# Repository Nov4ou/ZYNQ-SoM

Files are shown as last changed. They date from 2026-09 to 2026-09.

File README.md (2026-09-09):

# ZYNQ-SoM

An open-source Zynq-7000 system-on-module, designed in KiCad. The Rev B boards have been assembled and tested.

## Photos

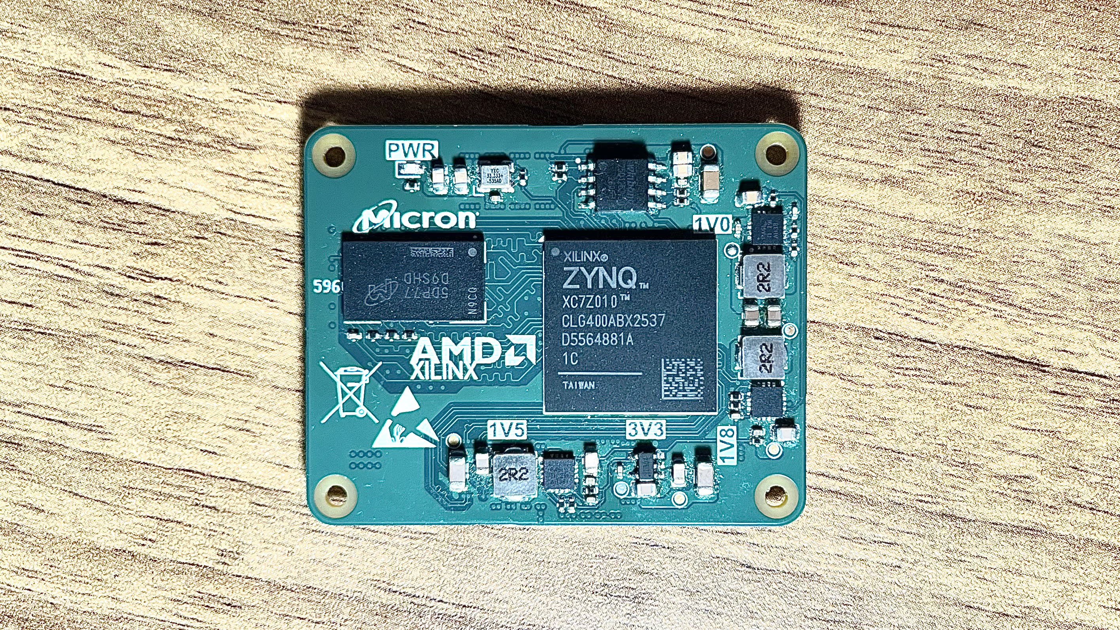
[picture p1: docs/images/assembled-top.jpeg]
Assembled ZYNQ-SoM top side


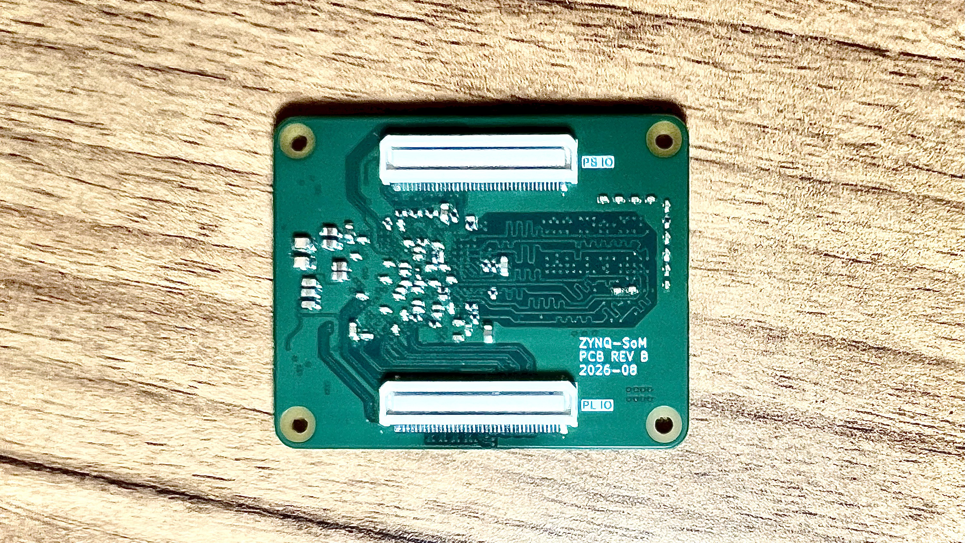
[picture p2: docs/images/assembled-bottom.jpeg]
Assembled ZYNQ-SoM bottom side


## What is on the board

- AMD/Xilinx XC7Z010-1CLG400C
- 512 MiB DDR3 (Micron MT41K256M16)
- 32 MiB QSPI NOR flash (Winbond W25Q256)
- 33.3333 MHz PS reference clock
- Two Panasonic AXK580137YG 80-pin board-to-board receptacles
- 50 mm × 40 mm, 6-layer PCB
- Separate PL Bank 34 and Bank 35 I/O voltage inputs
- 5 V module input with on-board power rails

The bottom-side silkscreen labels the connectors `PL IO` and `PS IO`. J402 carries PS MIO, configuration/JTAG, and PL Bank 35. J403 carries PL Bank 34 and module power-related pins.

## Files

```text
hardware/kicad/        KiCad project, schematic, PCB, symbols, footprints, and 3D models
docs/                  Schematic PDF, schematic page images, photos, and connector lengths
production/bom/        BOM exported from KiCad
production/gerbers/    Gerber and drill files
```

Open [hardware/kicad/ZYNQ-SoM.kicad_pro](hardware/kicad/ZYNQ-SoM.kicad_pro) with KiCad 10.0 or newer. Project symbols, footprints, and 3D models are referenced relative to `${KIPRJMOD}`, so no global custom-library setup is required.

## Useful files

- [SoM connector routing lengths](docs/connector-routing-lengths.md)
- [Machine-readable routing lengths](docs/connector-routing-lengths.csv)
- [Schematic PDF](docs/ZYNQ-SoM-schematic.pdf)
- [Gerber ZIP](production/gerbers/ZYNQ-SoM.zip)
- [BOM](production/bom/ZYNQ-SoM.csv)

The connector length table is for carrier-board length matching. It uses KiCad Net Inspector style lengths for the SoM-side routing; connector contact length and carrier-board routing are not included.

## Notes

- The checked-in Gerbers are the fabrication files for this revision.
- Review the KiCad source before ordering boards or changing parts.

## License

Released under the CERN Open Hardware Licence Version 2 - Permissive (`CERN-OHL-P-2.0`). See [LICENSE](LICENSE).

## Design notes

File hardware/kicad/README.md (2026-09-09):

# KiCad source

Open `ZYNQ-SoM.kicad_pro` with KiCad 10.0 or newer.

- `ZYNQ-SoM.kicad_sch` is the root schematic.
- `sheets/` contains the hierarchical schematic sheets.
- `ZYNQ-SoM.kicad_pcb` is the six-layer board layout.
- `ZYNQ-SoM.kicad_dru` contains project design rules.
- `lib/` contains the project-local KiCad symbols, `.pretty` footprint library, and 3D models.

Library tables use `${KIPRJMOD}` paths, so the project should be portable after cloning.

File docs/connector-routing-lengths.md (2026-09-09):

<!-- Generated by scripts/kicad_connector_lengths.py; do not edit by hand. -->

# SoM connector routing lengths

## J402 — PS MIO, configuration/JTAG, and PL Bank 35

| Pin | Domain | Net | Zynq ball | Net total (mm) | Carrier reference (mm) | Track/group (mm) | Via/group (mm) | Vias | Note |
|---:|---|---|---:|---:|---:|---:|---:|---:|---|
| 3 | PS | `OTG_DATA3` | F12 | 24.0515 | 24.0515 | 22.5131 | 1.5384 | 2 |  |
| 4 | Config/JTAG | `TDI` | G6 | 33.5430 | 33.5430 | 32.0046 | 1.5384 | 2 |  |
| 5 | PS | `OTG_DATA5` | A10 | 23.3860 | 23.3860 | 21.8476 | 1.5384 | 2 |  |
| 6 | Config/JTAG | `TDO` | F6 | 33.4415 | 33.4415 | 31.9031 | 1.5384 | 2 |  |
| 7 | PS | `OTG_CLK` | A11 | 22.8722 | 22.8722 | 21.3338 | 1.5384 | 2 |  |
| 8 | Config/JTAG | `TMS` | J6 | 36.2012 | 36.2012 | 34.6628 | 1.5384 | 2 |  |
| 9 | PS | `OTG_DATA6` | E13 | 24.5908 | 24.5908 | 23.0524 | 1.5384 | 2 |  |
| 10 | Config/JTAG | `TCK` | F9 | 34.4557 | 34.4557 | 32.9173 | 1.5384 | 2 |  |
| 13 | PS | `OTG_DIR` | C13 | 23.1948 | 23.1948 | 21.6564 | 1.5384 | 2 |  |
| 14 | PS | `PS_MIO47` | B14 | 26.6540 | 26.6540 | 25.1156 | 1.5384 | 2 |  |
| 15 | PS | `OTG_DATA1` | D15 | 22.7392 | 22.7392 | 21.2008 | 1.5384 | 2 |  |
| 16 | PS | `PS_MIO49` | C12 | 29.4419 | 29.4419 | 27.9035 | 1.5384 | 2 |  |
| 17 | PS | `OTG_STP` | C15 | 23.6819 | 23.6819 | 22.1435 | 1.5384 | 2 |  |
| 18 | PS | `PS_MIO27` | D13 | 31.3419 | 31.3419 | 29.8035 | 1.5384 | 2 |  |
| 19 | PS | `OTG_DATA0` | A14 | 23.3684 | 23.3684 | 21.8300 | 1.5384 | 2 |  |
| 20 | PS | `PS_MIO23` | D11 | 33.8526 | 33.8526 | 32.3142 | 1.5384 | 2 |  |
| 23 | PS | `OTG_DATA7` | C18 | 25.9201 | 25.9201 | 24.3817 | 1.5384 | 2 |  |
| 24 | PS | `PS_MIO21` | F14 | 31.1343 | 31.1343 | 29.5959 | 1.5384 | 2 |  |
| 25 | PS | `OTG_DATA2` | A12 | 23.0665 | 23.0665 | 21.5281 | 1.5384 | 2 |  |
| 26 | PS | `PS_MIO17` | E14 | 32.4486 | 32.4486 | 30.9102 | 1.5384 | 2 |  |
| 27 | PS | `OTG_NXT` | E16 | 25.7201 | 25.7201 | 24.1817 | 1.5384 | 2 |  |
| 28 | PS | `PS_MIO25` | F15 | 32.6699 | 32.6699 | 31.1315 | 1.5384 | 2 |  |
| 29 | PS | `OTG_DATA4` | C16 | 25.5061 | 25.5061 | 23.9677 | 1.5384 | 2 |  |
| 30 | PS | `PS_MIO19` | D10 | 40.6493 | 40.6493 | 39.1109 | 1.5384 | 2 |  |
| 33 | PS | `OTG_nRST` | D16 | 23.9272 | 23.9272 | 22.3888 | 1.5384 | 2 |  |
| 34 | PS | `PS_POR_B` | C7 | 45.2190 | 45.2190 | 43.6806 | 1.5384 | 2 |  |
| 35 | PS | `PS_MIO53` | C11 | 21.2515 | 21.2515 | 19.7131 | 1.5384 | 2 |  |
| 36 | Config/JTAG | `DONE` | R11 | 39.0910 | 39.0910 | 36.7214 | 2.3696 | 2 | branched net; total includes every routed branch |
| 37 | PS | `PS_MIO48` | B12 | 16.6845 | 16.6845 | 15.1461 | 1.5384 | 2 |  |
| 38 | PS | `SD_DATA1` | A9 | 16.4654 | 16.4654 | 14.9270 | 1.5384 | 1 |  |
| 39 | PS | `PS_MIO52` | C10 | 16.1988 | 16.1988 | 14.6603 | 1.5384 | 2 |  |
| 40 | PS | `SD_DATA3` | B15 | 20.9649 | 20.9649 | 19.4265 | 1.5384 | 1 |  |
| 43 | PS | `PS_MIO18` | B18 | 27.6247 | 27.6247 | 26.0863 | 1.5384 | 1 |  |
| 44 | PS | `SD_CMD` | C17 | 24.5302 | 24.5302 | 22.9918 | 1.5384 | 1 |  |
| 45 | PS | `PS_MIO16` | A19 | 23.8285 | 23.8285 | 22.2901 | 1.5384 | 1 |  |
| 46 | PS | `SD_DATA2` | F13 | 35.7699 | 35.7699 | 34.2315 | 1.5384 | 1 |  |
| 47 | PS | `UART_RX` | C5 | 8.0976 | 8.0976 | 6.5592 | 1.5384 | 1 |  |
| 48 | PS | `SD_DATA0` | E12 | 33.8456 | 33.8456 | 32.3072 | 1.5384 | 1 |  |
| 49 | PS | `UART_TX` | C8 | 10.0683 | 10.0683 | 8.5299 | 1.5384 | 1 |  |
| 50 | PS | `SD_CLK` | D14 | 24.9918 | 28.3101 | 26.7717 | 1.5384 | 1 | sum of both nets across R703; resistor body excluded |
| 53 | PS | `QSPI_D3_PS_MIO5` | A6 | 17.5968 | 17.5968 | 14.5200 | 3.0768 | 2 | branched net; total includes every routed branch |
| 54 | PL B35 | `PL_B35_IO14_P` | J18 | 36.5494 | 36.5494 | 35.0110 | 1.5384 | 2 |  |
| 55 | PS | `QSPI_D2_PS_MIO4` | B7 | 9.5668 | 9.5668 | 8.0284 | 1.5384 | 1 | branched net; total includes every routed branch |
| 56 | PL B35 | `PL_B35_IO14_N` | H18 | 36.2826 | 36.2826 | 34.7442 | 1.5384 | 2 |  |
| 57 | PS | `I2C0_SDA` | B9 | 7.5875 | 7.5875 | 6.0491 | 1.5384 | 1 |  |
| 58 | PL B35 | `PL_B35_IO11_P` | L16 | 35.9842 | 35.9842 | 34.4458 | 1.5384 | 2 |  |
| 59 | PS | `I2C0_SCL` | B13 | 10.2096 | 10.2096 | 8.6712 | 1.5384 | 1 |  |
| 60 | PL B35 | `PL_B35_IO11_N` | L17 | 35.9842 | 35.9842 | 34.4458 | 1.5384 | 2 |  |
| 63 | PS | `PS_MIO26` | A15 | 9.6935 | 9.6935 | 8.1551 | 1.5384 | 1 |  |
| 64 | PL B35 | `PL_B35_IO7_P` | M19 | 35.9937 | 35.9937 | 34.4553 | 1.5384 | 2 |  |
| 65 | PS | `PS_MIO24` | A16 | 9.7824 | 9.7824 | 8.2440 | 1.5384 | 1 |  |
| 66 | PL B35 | `PL_B35_IO7_N` | M20 | 35.9937 | 35.9937 | 34.4553 | 1.5384 | 2 |  |
| 67 | PS | `PS_MIO20` | A17 | 15.8331 | 15.8331 | 14.2947 | 1.5384 | 1 |  |
| 68 | PL B35 | `PL_B35_IO9_P` | L19 | 35.3043 | 35.3043 | 33.7659 | 1.5384 | 2 |  |
| 69 | PS | `PS_MIO22` | B17 | 10.0895 | 10.0895 | 8.5511 | 1.5384 | 1 |  |
| 70 | PL B35 | `PL_B35_IO9_N` | L20 | 35.3043 | 35.3043 | 33.7659 | 1.5384 | 2 |  |

## J403 — PL Bank 34

| Pin | Domain | Net | Zynq ball | Net total (mm) | Carrier reference (mm) | Track/group (mm) | Via/group (mm) | Vias | Note |
|---:|---|---|---:|---:|---:|---:|---:|---:|---|
| 3 | PL B34 | `PL_B34_IO7_N` | Y17 | 38.7952 | 38.7952 | 37.2568 | 1.5384 | 1 |  |
| 4 | PL B34 | `PL_B34_IO16_N` | W20 | 30.7718 | 30.7718 | 29.2334 | 1.5384 | 1 |  |
| 5 | PL B34 | `PL_B34_IO7_P` | Y16 | 38.7952 | 38.7952 | 37.2568 | 1.5384 | 1 |  |
| 6 | PL B34 | `PL_B34_IO16_P` | V20 | 30.7718 | 30.7718 | 29.2334 | 1.5384 | 1 |  |
| 9 | PL B34 | `PL_B34_IO17_N` | Y19 | 38.1787 | 38.1787 | 36.6403 | 1.5384 | 1 |  |
| 10 | PL B34 | `PL_B34_IO15_N` | U20 | 32.0038 | 32.0038 | 30.4654 | 1.5384 | 1 |  |
| 11 | PL B34 | `PL_B34_IO17_P` | Y18 | 38.0117 | 38.0117 | 36.4733 | 1.5384 | 1 |  |
| 12 | PL B34 | `PL_B34_IO15_P` | T20 | 32.0038 | 32.0038 | 30.4654 | 1.5384 | 1 |  |
| 15 | PL B34 | `PL_B34_IO1_N` | T10 | 39.3649 | 39.3649 | 37.8265 | 1.5384 | 2 |  |
| 16 | PL B34 | `PL_B34_IO3_P` | U13 | 22.6339 | 22.6339 | 21.0955 | 1.5384 | 1 |  |
| 17 | PL B34 | `PL_B34_IO1_P` | T11 | 39.4928 | 39.4928 | 37.9544 | 1.5384 | 2 |  |
| 18 | PL B34 | `PL_B34_IO3_N` | V13 | 22.4925 | 22.4925 | 20.9541 | 1.5384 | 1 |  |
| 21 | PL B34 | `PL_B34_IO2_N` | U12 | 40.0834 | 40.0834 | 38.5450 | 1.5384 | 2 |  |
| 22 | PL B34 | `PL_B34_IO8_P` | W14 | 20.0018 | 20.0018 | 18.4634 | 1.5384 | 1 |  |
| 23 | PL B34 | `PL_B34_IO2_P` | T12 | 40.0834 | 40.0834 | 38.5450 | 1.5384 | 2 |  |
| 24 | PL B34 | `PL_B34_IO8_N` | Y14 | 19.9867 | 19.9867 | 18.4483 | 1.5384 | 1 |  |
| 27 | PL B34 | `PL_B34_IO4_P` | V12 | 39.3740 | 39.3740 | 37.7116 | 1.6624 | 2 |  |
| 28 | PL B34 | `PL_B34_IO11_P` | U14 | 22.4945 | 22.4945 | 20.9561 | 1.5384 | 1 |  |
| 29 | PL B34 | `PL_B34_IO4_N` | W13 | 39.3825 | 39.3825 | 37.7201 | 1.6624 | 2 |  |
| 30 | PL B34 | `PL_B34_IO11_N` | U15 | 22.3716 | 22.3716 | 20.8332 | 1.5384 | 1 |  |
| 33 | PL B34 | `PL_B34_IO9_P` | T16 | 44.8547 | 44.8547 | 43.1923 | 1.6624 | 2 |  |
| 34 | PL B34 | `PL_B34_IO5_P` | T14 | 18.9993 | 18.9993 | 17.4609 | 1.5384 | 2 |  |
| 35 | PL B34 | `PL_B34_IO9_N` | U17 | 44.8461 | 44.8461 | 43.1837 | 1.6624 | 2 |  |
| 36 | PL B34 | `PL_B34_IO5_N` | T15 | 18.9993 | 18.9993 | 17.4609 | 1.5384 | 2 |  |
| 39 | PL B34 | `PL_B34_IO20_P` | T17 | 38.1690 | 38.1690 | 36.6306 | 1.5384 | 2 |  |
| 40 | PL B34 | `PL_B34_IO14_P` | N20 | 38.0472 | 38.0472 | 36.5089 | 1.5384 | 1 |  |
| 41 | PL B34 | `PL_B34_IO20_N` | R18 | 38.1457 | 38.1457 | 36.6073 | 1.5384 | 2 |  |
| 42 | PL B34 | `PL_B34_IO14_N` | P20 | 38.0473 | 38.0473 | 36.5089 | 1.5384 | 1 |  |
| 45 | PL B34 | `PL_B34_IO21_P` | V17 | 31.8645 | 31.8645 | 30.3261 | 1.5384 | 2 |  |
| 46 | PL B34 | `PL_B34_IO13_P` | N18 | 29.8043 | 29.8043 | 28.2659 | 1.5384 | 1 |  |
| 47 | PL B34 | `PL_B34_IO21_N` | V18 | 32.0632 | 32.0632 | 30.5248 | 1.5384 | 2 |  |
| 48 | PL B34 | `PL_B34_IO13_N` | P19 | 29.7957 | 29.7957 | 28.2573 | 1.5384 | 1 |  |
| 51 | PL B34 | `PL_B34_IO12_N` | U19 | 31.8816 | 31.8816 | 30.3432 | 1.5384 | 2 |  |
| 52 | PL B34 | `PL_B34_IO22_P` | W18 | 16.7702 | 16.7702 | 15.2318 | 1.5384 | 1 |  |
| 53 | PL B34 | `PL_B34_IO12_P` | U18 | 32.0802 | 32.0802 | 30.5418 | 1.5384 | 2 |  |
| 54 | PL B34 | `PL_B34_IO22_N` | W19 | 16.7702 | 16.7702 | 15.2318 | 1.5384 | 1 |  |
| 57 | PL B34 | `PL_B34_IO19_N` | R17 | 32.3187 | 32.3187 | 30.7803 | 1.5384 | 2 |  |
| 58 | PL B34 | `PL_B34_IO10_N` | W15 | 19.5445 | 19.5445 | 18.0061 | 1.5384 | 2 |  |
| 59 | PL B34 | `PL_B34_IO19_P` | R16 | 32.3187 | 32.3187 | 30.7803 | 1.5384 | 2 |  |
| 60 | PL B34 | `PL_B34_IO10_P` | V15 | 19.5445 | 19.5445 | 18.0061 | 1.5384 | 2 |  |
| 63 | PL B34 | `PL_B34_IO23_N` | P18 | 32.3217 | 32.3217 | 30.7833 | 1.5384 | 2 |  |
| 64 | PL B34 | `PL_B34_IO18_P` | V16 | 18.8678 | 18.8678 | 17.3294 | 1.5384 | 2 |  |
| 65 | PL B34 | `PL_B34_IO23_P` | N17 | 32.3132 | 32.3132 | 30.7748 | 1.5384 | 2 |  |
| 66 | PL B34 | `PL_B34_IO18_N` | W16 | 18.9842 | 18.9842 | 17.4458 | 1.5384 | 2 |  |

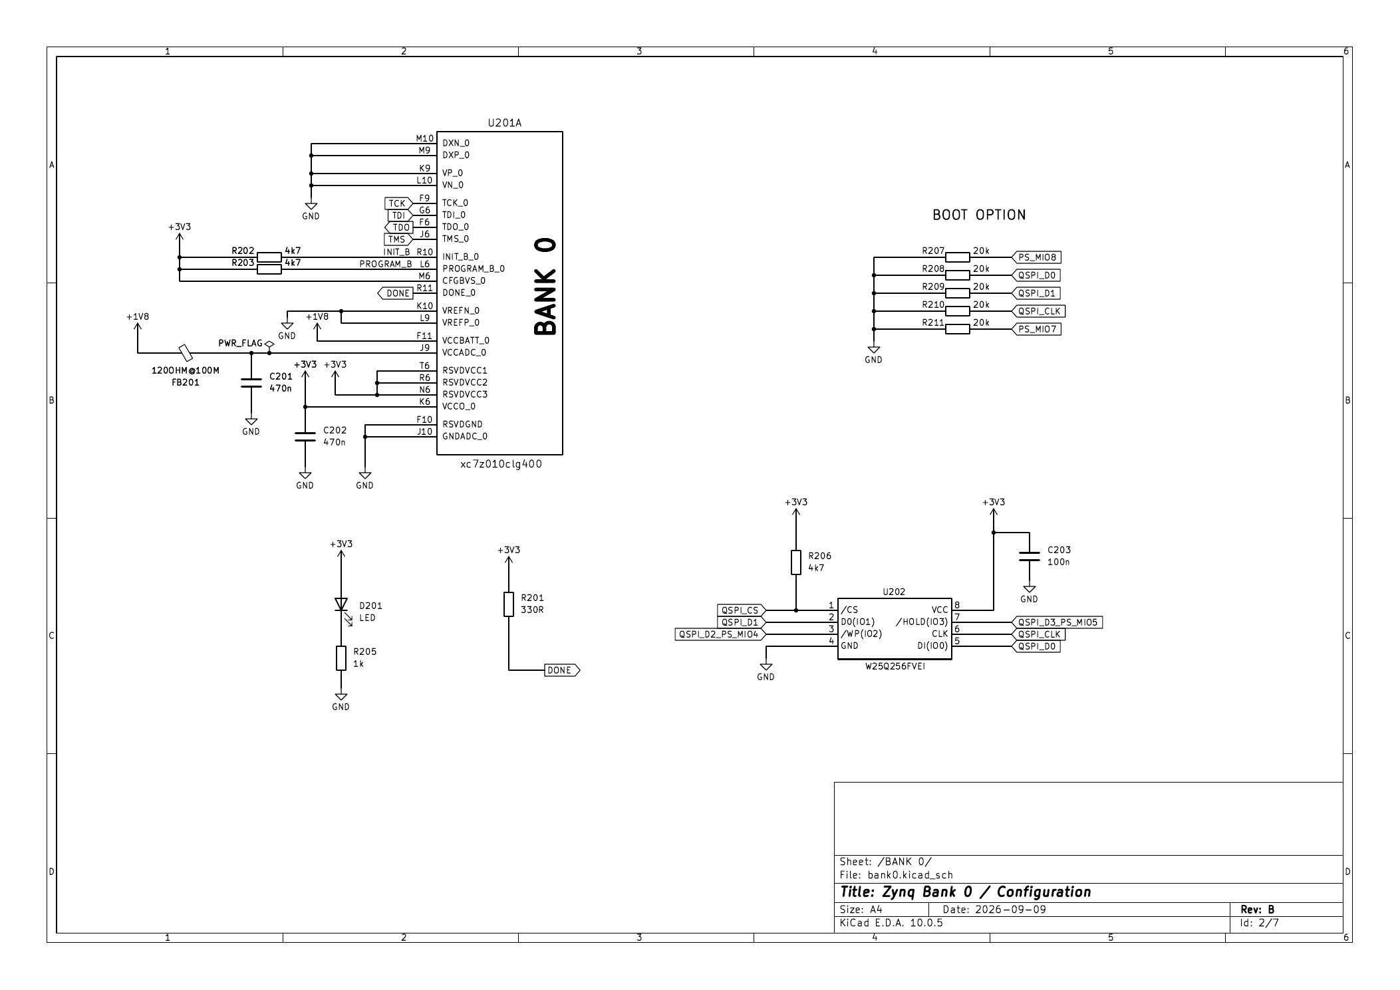
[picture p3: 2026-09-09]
docs/images/schematic-pages/zynq-2.png

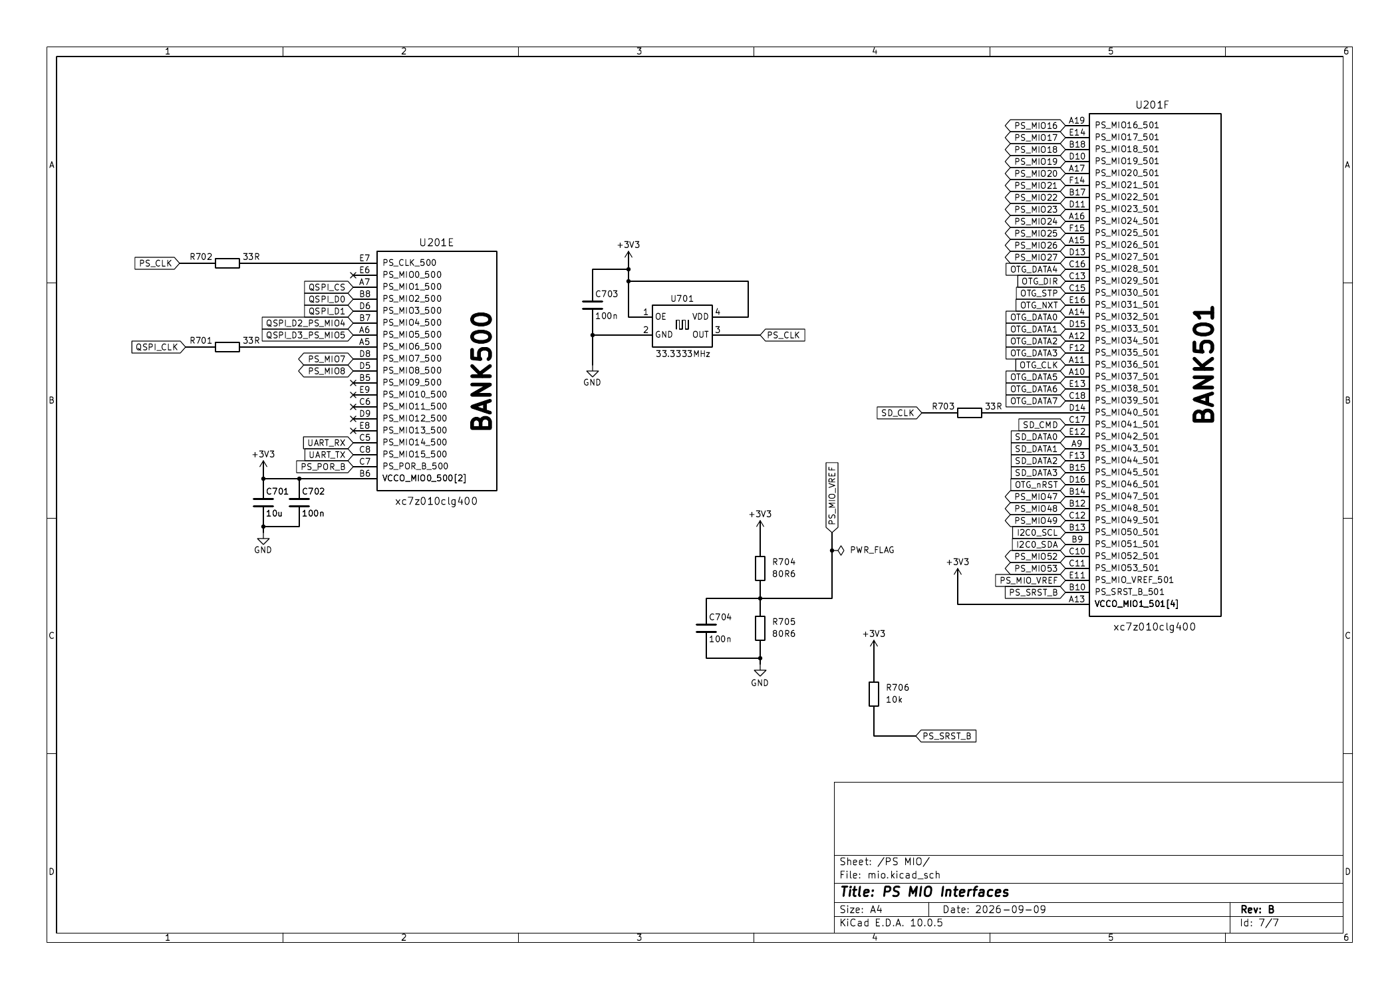
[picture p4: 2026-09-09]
docs/images/schematic-pages/zynq-7.png

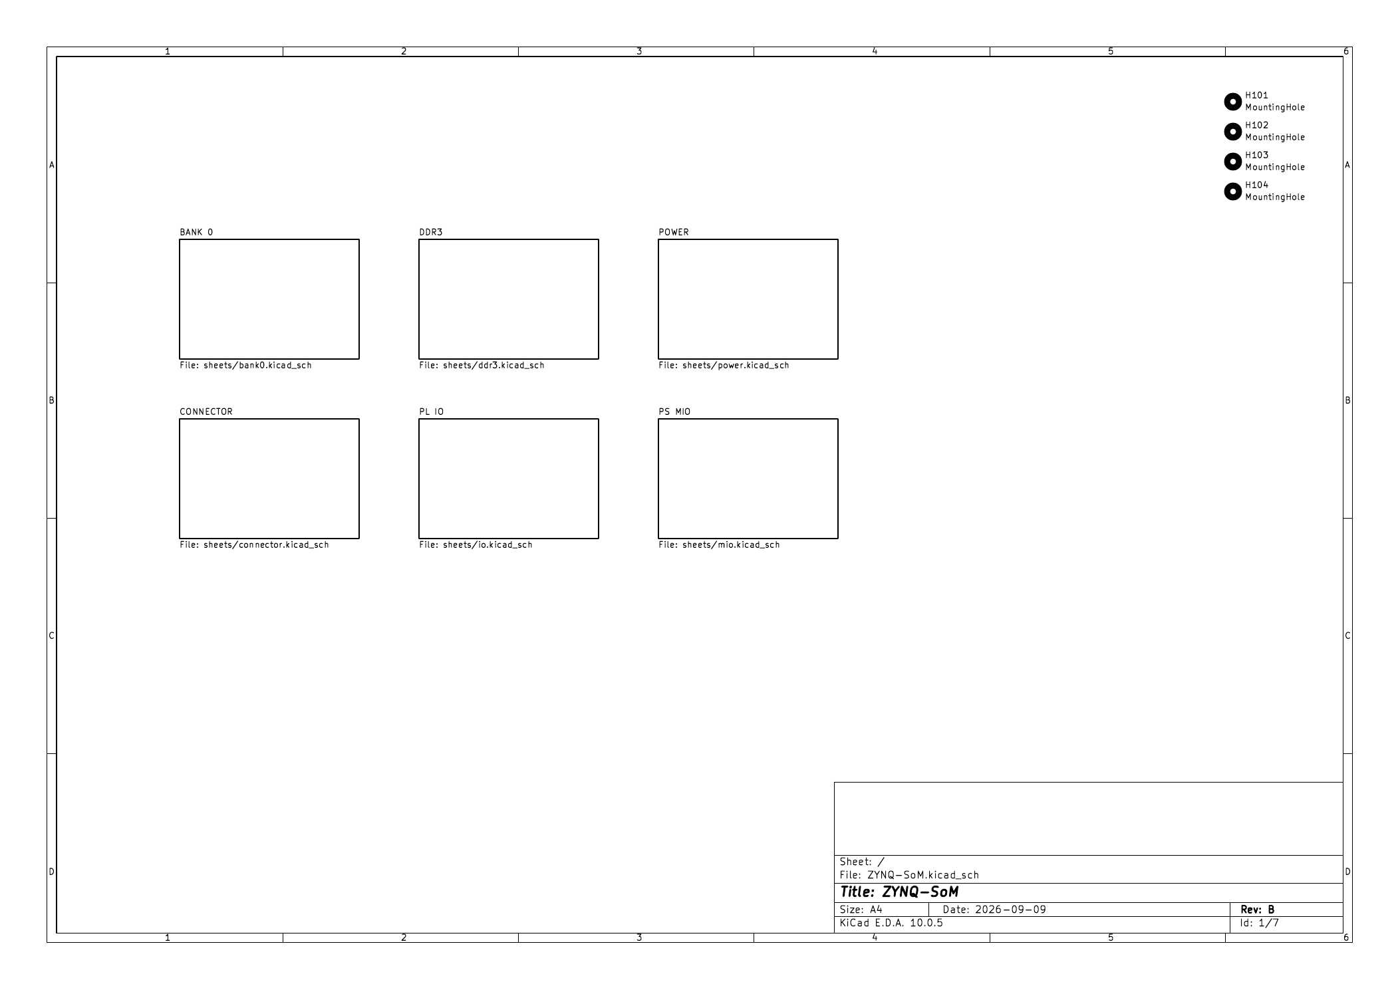
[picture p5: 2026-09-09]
docs/images/schematic-pages/zynq-1.png

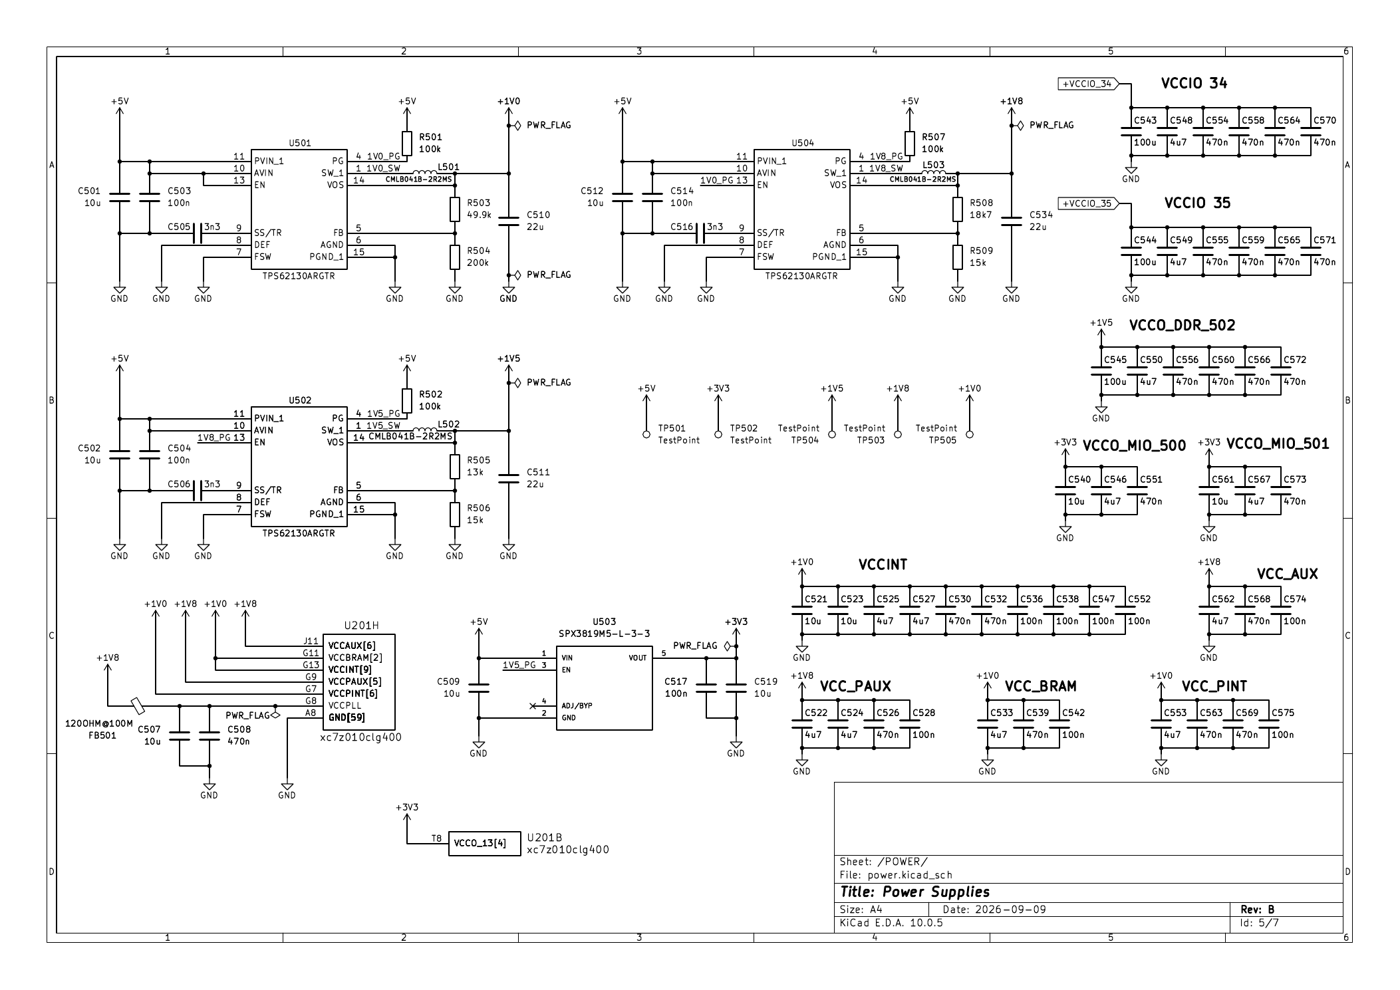
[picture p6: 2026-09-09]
docs/images/schematic-pages/zynq-5.png

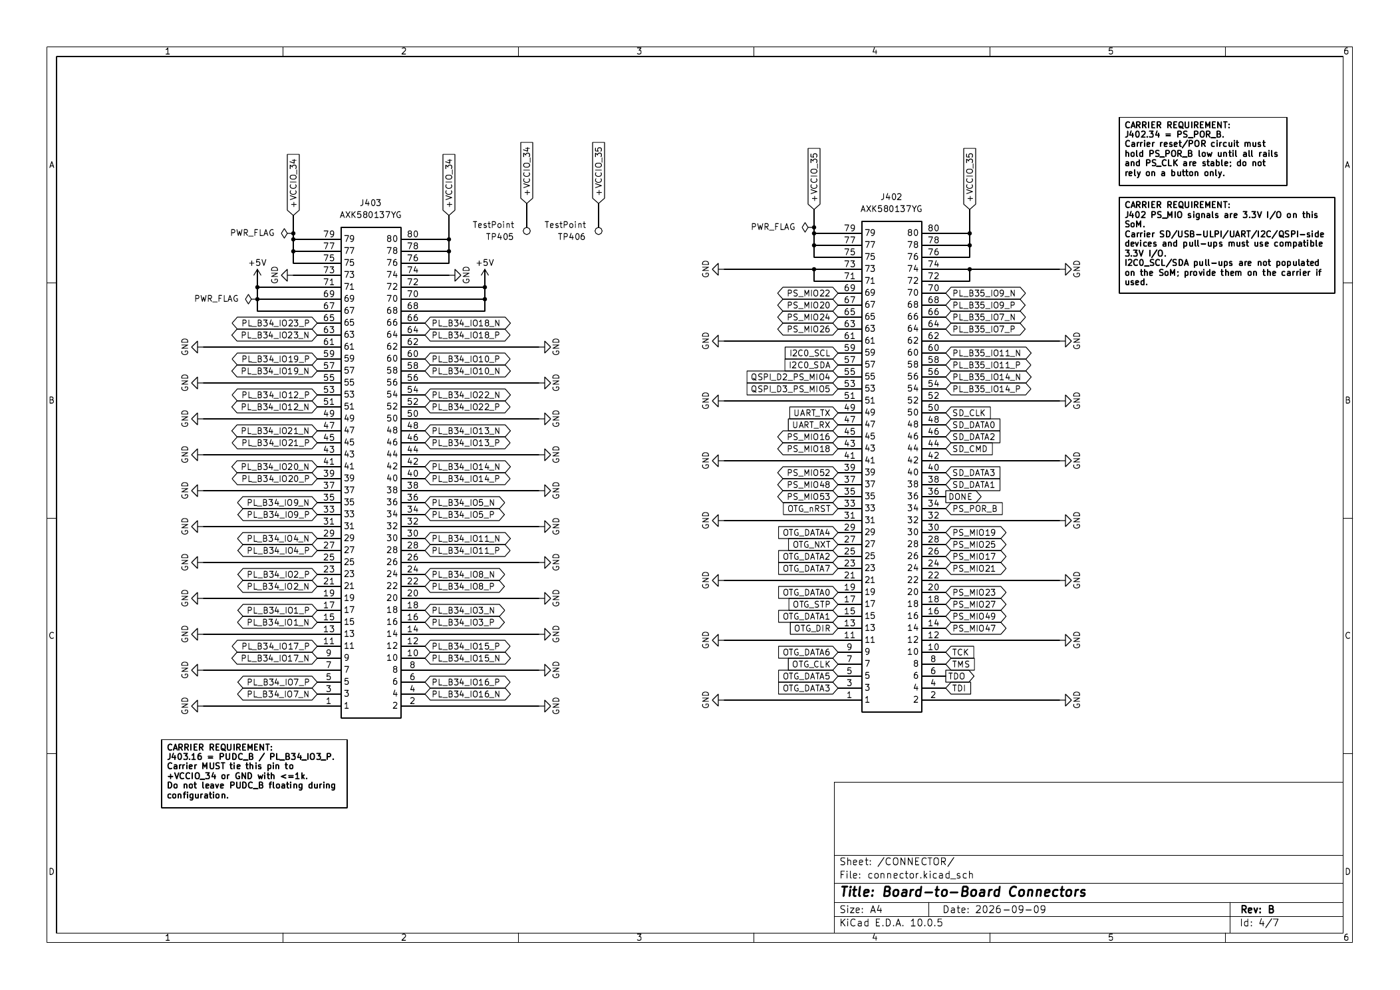
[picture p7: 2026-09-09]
docs/images/schematic-pages/zynq-4.png

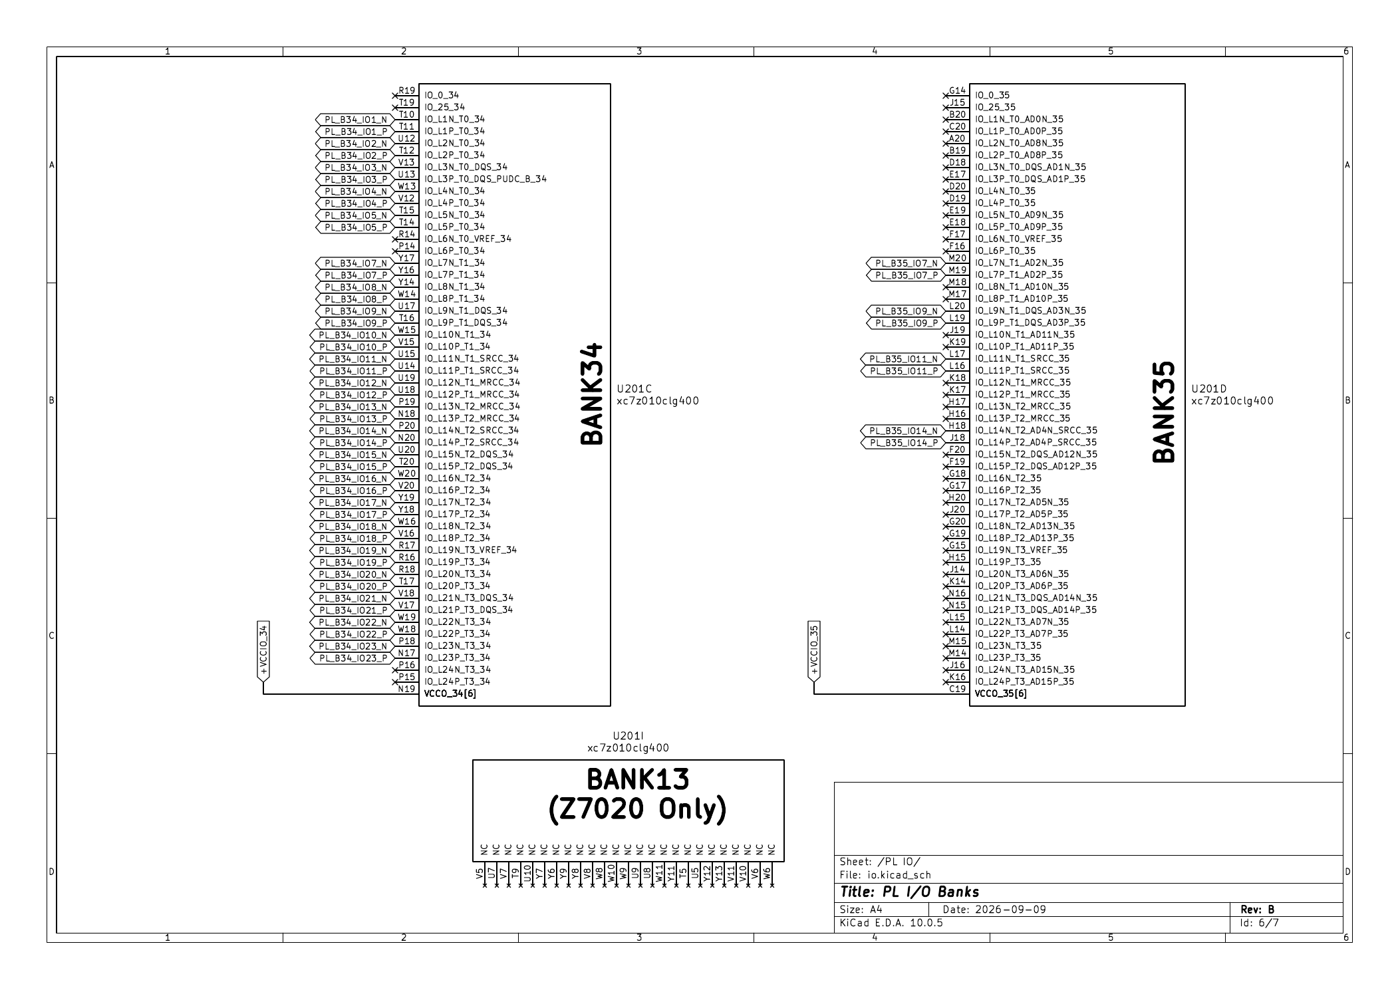
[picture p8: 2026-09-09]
docs/images/schematic-pages/zynq-6.png

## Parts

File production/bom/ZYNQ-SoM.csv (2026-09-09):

Refs | Value | Footprint | Qty | DNP
C201,C202,C508,C526,C530,C532,C539,C551,C554-C556,C558-C560,C563-C566,C568-C573 | 470n | Capacitor_SMD:C_0402_1005Metric | 24
C203,C301-C314,C503,C504,C514,C517,C528,C536,C538,C542,C547,C552,C574,C575,C702-C704 | 100n | Capacitor_SMD:C_0402_1005Metric | 30
C501,C502,C509,C512,C519,C521,C523,C561,C701 | 10u | Capacitor_SMD:C_0805_2012Metric | 9
C505,C506,C516 | 3n3 | Capacitor_SMD:C_0402_1005Metric | 3
C507,C540 | 10u | Capacitor_SMD:C_0603_1608Metric | 2
C510,C511,C534 | 22u | Capacitor_SMD:C_0805_2012Metric | 3
C522,C524,C525,C527,C533,C546,C548-C550,C553,C562,C567 | 4u7 | Capacitor_SMD:C_0603_1608Metric | 12
C543-C545 | 100u | Capacitor_SMD:C_1206_3216Metric | 3
D201 | LED | LED_SMD:LED_0603_1608Metric | 1
FB201,FB501 | 120OHM@100M | Inductor_SMD:L_0402_1005Metric | 2
J402,J403 | AXK580137YG | Project:AXK580137YG | 2
L501-L503 | CMLB041B-2R2MS | Project:IND_CMLB041B-1R0MS | 3
R201 | 330R | Resistor_SMD:R_0402_1005Metric | 1
R202,R203,R206,R302 | 4k7 | Resistor_SMD:R_0402_1005Metric | 4
R205 | 1k | Resistor_SMD:R_0402_1005Metric | 1
R207-R211 | 20k | Resistor_SMD:R_0402_1005Metric | 5
R301 | 240R | Resistor_SMD:R_0402_1005Metric | 1
R303-R309,R704,R705 | 80R6 | Resistor_SMD:R_0402_1005Metric | 9
R501,R502,R507 | 100k | Resistor_SMD:R_0402_1005Metric | 3
R503 | 49.9k | Resistor_SMD:R_0402_1005Metric | 1
R504 | 200k | Resistor_SMD:R_0402_1005Metric | 1
R505 | 13k | Resistor_SMD:R_0402_1005Metric | 1
R506,R509 | 15k | Resistor_SMD:R_0402_1005Metric | 2
R508 | 18k7 | Resistor_SMD:R_0402_1005Metric | 1
R701-R703 | 33R | Resistor_SMD:R_0402_1005Metric | 3
R706 | 10k | Resistor_SMD:R_0402_1005Metric | 1
TP405,TP406,TP501-TP505 | TestPoint | TestPoint:TestPoint_Pad_D1.0mm | 7
U201 | xc7z010clg400 | Package_BGA:Xilinx_CLG400 | 1
U202 | W25Q256FVEI | Project:SON127P800X600X80-9N-D | 1
U301 | MT41K256M16TW-107_P | Project:BGA96C80P9X16_1400X800X120 | 1
U501,U502,U504 | TPS62130ARGTR | Project:QFN50P300X300X100-17N-D | 3
U503 | SPX3819M5-L-3-3 | Project:SPX3819M5-L-3-3 | 1
U701 | 33.3333MHz | Oscillator:Oscillator_SMD_SeikoEpson_SG8002CE-4Pin_3.2x2.5mm | 1

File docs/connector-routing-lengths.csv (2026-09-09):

connector | pin | domain | net | path_nets | zynq_pad | net_inspector_total_mm | carrier_reference_total_mm | track_length_mm | via_count | via_length_mm | die_length_mm | pad_count | connected_pads | notes
J402 | 3 | PS | OTG_DATA3 | OTG_DATA3 | F12 | 24.0515 | 24.0515 | 22.5131 | 2 | 1.5384 | 0.0000 | 2 | U201.F12;J402.3
J402 | 4 | Config/JTAG | TDI | TDI | G6 | 33.5430 | 33.5430 | 32.0046 | 2 | 1.5384 | 0.0000 | 2 | U201.G6;J402.4
J402 | 5 | PS | OTG_DATA5 | OTG_DATA5 | A10 | 23.3860 | 23.3860 | 21.8476 | 2 | 1.5384 | 0.0000 | 2 | U201.A10;J402.5
J402 | 6 | Config/JTAG | TDO | TDO | F6 | 33.4415 | 33.4415 | 31.9031 | 2 | 1.5384 | 0.0000 | 2 | U201.F6;J402.6
J402 | 7 | PS | OTG_CLK | OTG_CLK | A11 | 22.8722 | 22.8722 | 21.3338 | 2 | 1.5384 | 0.0000 | 2 | U201.A11;J402.7
J402 | 8 | Config/JTAG | TMS | TMS | J6 | 36.2012 | 36.2012 | 34.6628 | 2 | 1.5384 | 0.0000 | 2 | U201.J6;J402.8
J402 | 9 | PS | OTG_DATA6 | OTG_DATA6 | E13 | 24.5908 | 24.5908 | 23.0524 | 2 | 1.5384 | 0.0000 | 2 | U201.E13;J402.9
J402 | 10 | Config/JTAG | TCK | TCK | F9 | 34.4557 | 34.4557 | 32.9173 | 2 | 1.5384 | 0.0000 | 2 | U201.F9;J402.10
J402 | 13 | PS | OTG_DIR | OTG_DIR | C13 | 23.1948 | 23.1948 | 21.6564 | 2 | 1.5384 | 0.0000 | 2 | U201.C13;J402.13
J402 | 14 | PS | PS_MIO47 | PS_MIO47 | B14 | 26.6540 | 26.6540 | 25.1156 | 2 | 1.5384 | 0.0000 | 2 | U201.B14;J402.14
J402 | 15 | PS | OTG_DATA1 | OTG_DATA1 | D15 | 22.7392 | 22.7392 | 21.2008 | 2 | 1.5384 | 0.0000 | 2 | U201.D15;J402.15
J402 | 16 | PS | PS_MIO49 | PS_MIO49 | C12 | 29.4419 | 29.4419 | 27.9035 | 2 | 1.5384 | 0.0000 | 2 | U201.C12;J402.16
J402 | 17 | PS | OTG_STP | OTG_STP | C15 | 23.6819 | 23.6819 | 22.1435 | 2 | 1.5384 | 0.0000 | 2 | U201.C15;J402.17
J402 | 18 | PS | PS_MIO27 | PS_MIO27 | D13 | 31.3419 | 31.3419 | 29.8035 | 2 | 1.5384 | 0.0000 | 2 | U201.D13;J402.18
J402 | 19 | PS | OTG_DATA0 | OTG_DATA0 | A14 | 23.3684 | 23.3684 | 21.8300 | 2 | 1.5384 | 0.0000 | 2 | U201.A14;J402.19
J402 | 20 | PS | PS_MIO23 | PS_MIO23 | D11 | 33.8526 | 33.8526 | 32.3142 | 2 | 1.5384 | 0.0000 | 2 | U201.D11;J402.20
J402 | 23 | PS | OTG_DATA7 | OTG_DATA7 | C18 | 25.9201 | 25.9201 | 24.3817 | 2 | 1.5384 | 0.0000 | 2 | U201.C18;J402.23
J402 | 24 | PS | PS_MIO21 | PS_MIO21 | F14 | 31.1343 | 31.1343 | 29.5959 | 2 | 1.5384 | 0.0000 | 2 | U201.F14;J402.24
J402 | 25 | PS | OTG_DATA2 | OTG_DATA2 | A12 | 23.0665 | 23.0665 | 21.5281 | 2 | 1.5384 | 0.0000 | 2 | U201.A12;J402.25
J402 | 26 | PS | PS_MIO17 | PS_MIO17 | E14 | 32.4486 | 32.4486 | 30.9102 | 2 | 1.5384 | 0.0000 | 2 | U201.E14;J402.26
J402 | 27 | PS | OTG_NXT | OTG_NXT | E16 | 25.7201 | 25.7201 | 24.1817 | 2 | 1.5384 | 0.0000 | 2 | U201.E16;J402.27
J402 | 28 | PS | PS_MIO25 | PS_MIO25 | F15 | 32.6699 | 32.6699 | 31.1315 | 2 | 1.5384 | 0.0000 | 2 | U201.F15;J402.28
J402 | 29 | PS | OTG_DATA4 | OTG_DATA4 | C16 | 25.5061 | 25.5061 | 23.9677 | 2 | 1.5384 | 0.0000 | 2 | U201.C16;J402.29
J402 | 30 | PS | PS_MIO19 | PS_MIO19 | D10 | 40.6493 | 40.6493 | 39.1109 | 2 | 1.5384 | 0.0000 | 2 | U201.D10;J402.30
J402 | 33 | PS | OTG_nRST | OTG_nRST | D16 | 23.9272 | 23.9272 | 22.3888 | 2 | 1.5384 | 0.0000 | 2 | U201.D16;J402.33
J402 | 34 | PS | PS_POR_B | PS_POR_B | C7 | 45.2190 | 45.2190 | 43.6806 | 2 | 1.5384 | 0.0000 | 2 | U201.C7;J402.34
J402 | 35 | PS | PS_MIO53 | PS_MIO53 | C11 | 21.2515 | 21.2515 | 19.7131 | 2 | 1.5384 | 0.0000 | 2 | U201.C11;J402.35
J402 | 36 | Config/JTAG | DONE | DONE | R11 | 39.0910 | 39.0910 | 36.7214 | 2 | 2.3696 | 0.0000 | 3 | U201.R11;R201.2;J402.36 | branched net; total includes every routed branch
J402 | 37 | PS | PS_MIO48 | PS_MIO48 | B12 | 16.6845 | 16.6845 | 15.1461 | 2 | 1.5384 | 0.0000 | 2 | U201.B12;J402.37
J402 | 38 | PS | SD_DATA1 | SD_DATA1 | A9 | 16.4654 | 16.4654 | 14.9270 | 1 | 1.5384 | 0.0000 | 2 | U201.A9;J402.38
J402 | 39 | PS | PS_MIO52 | PS_MIO52 | C10 | 16.1988 | 16.1988 | 14.6603 | 2 | 1.5384 | 0.0000 | 2 | U201.C10;J402.39
J402 | 40 | PS | SD_DATA3 | SD_DATA3 | B15 | 20.9649 | 20.9649 | 19.4265 | 1 | 1.5384 | 0.0000 | 2 | U201.B15;J402.40
J402 | 43 | PS | PS_MIO18 | PS_MIO18 | B18 | 27.6247 | 27.6247 | 26.0863 | 1 | 1.5384 | 0.0000 | 2 | U201.B18;J402.43
J402 | 44 | PS | SD_CMD | SD_CMD | C17 | 24.5302 | 24.5302 | 22.9918 | 1 | 1.5384 | 0.0000 | 2 | U201.C17;J402.44
J402 | 45 | PS | PS_MIO16 | PS_MIO16 | A19 | 23.8285 | 23.8285 | 22.2901 | 1 | 1.5384 | 0.0000 | 2 | U201.A19;J402.45
J402 | 46 | PS | SD_DATA2 | SD_DATA2 | F13 | 35.7699 | 35.7699 | 34.2315 | 1 | 1.5384 | 0.0000 | 2 | U201.F13;J402.46
J402 | 47 | PS | UART_RX | UART_RX | C5 | 8.0976 | 8.0976 | 6.5592 | 1 | 1.5384 | 0.0000 | 2 | U201.C5;J402.47
J402 | 48 | PS | SD_DATA0 | SD_DATA0 | E12 | 33.8456 | 33.8456 | 32.3072 | 1 | 1.5384 | 0.0000 | 2 | U201.E12;J402.48
J402 | 49 | PS | UART_TX | UART_TX | C8 | 10.0683 | 10.0683 | 8.5299 | 1 | 1.5384 | 0.0000 | 2 | U201.C8;J402.49
J402 | 50 | PS | SD_CLK | SD_CLK;Net-(U201F-PS_MIO40_501) | D14 | 24.9918 | 28.3101 | 26.7717 | 1 | 1.5384 | 0.0000 | 4 | R703.1;J402.50;U201.D14;R703.2 | sum of both nets across R703; resistor body excluded
J402 | 53 | PS | QSPI_D3_PS_MIO5 | QSPI_D3_PS_MIO5 | A6 | 17.5968 | 17.5968 | 14.5200 | 2 | 3.0768 | 0.0000 | 3 | U202.7;U201.A6;J402.53 | branched net; total includes every routed branch
J402 | 54 | PL B35 | PL_B35_IO14_P | PL_B35_IO14_P | J18 | 36.5494 | 36.5494 | 35.0110 | 2 | 1.5384 | 0.0000 | 2 | U201.J18;J402.54
J402 | 55 | PS | QSPI_D2_PS_MIO4 | QSPI_D2_PS_MIO4 | B7 | 9.5668 | 9.5668 | 8.0284 | 1 | 1.5384 | 0.0000 | 3 | U202.3;U201.B7;J402.55 | branched net; total includes every routed branch
J402 | 56 | PL B35 | PL_B35_IO14_N | PL_B35_IO14_N | H18 | 36.2826 | 36.2826 | 34.7442 | 2 | 1.5384 | 0.0000 | 2 | U201.H18;J402.56
J402 | 57 | PS | I2C0_SDA | I2C0_SDA | B9 | 7.5875 | 7.5875 | 6.0491 | 1 | 1.5384 | 0.0000 | 2 | U201.B9;J402.57
J402 | 58 | PL B35 | PL_B35_IO11_P | PL_B35_IO11_P | L16 | 35.9842 | 35.9842 | 34.4458 | 2 | 1.5384 | 0.0000 | 2 | U201.L16;J402.58
J402 | 59 | PS | I2C0_SCL | I2C0_SCL | B13 | 10.2096 | 10.2096 | 8.6712 | 1 | 1.5384 | 0.0000 | 2 | U201.B13;J402.59
J402 | 60 | PL B35 | PL_B35_IO11_N | PL_B35_IO11_N | L17 | 35.9842 | 35.9842 | 34.4458 | 2 | 1.5384 | 0.0000 | 2 | U201.L17;J402.60
J402 | 63 | PS | PS_MIO26 | PS_MIO26 | A15 | 9.6935 | 9.6935 | 8.1551 | 1 | 1.5384 | 0.0000 | 2 | U201.A15;J402.63
J402 | 64 | PL B35 | PL_B35_IO7_P | PL_B35_IO7_P | M19 | 35.9937 | 35.9937 | 34.4553 | 2 | 1.5384 | 0.0000 | 2 | U201.M19;J402.64
J402 | 65 | PS | PS_MIO24 | PS_MIO24 | A16 | 9.7824 | 9.7824 | 8.2440 | 1 | 1.5384 | 0.0000 | 2 | U201.A16;J402.65
J402 | 66 | PL B35 | PL_B35_IO7_N | PL_B35_IO7_N | M20 | 35.9937 | 35.9937 | 34.4553 | 2 | 1.5384 | 0.0000 | 2 | U201.M20;J402.66
J402 | 67 | PS | PS_MIO20 | PS_MIO20 | A17 | 15.8331 | 15.8331 | 14.2947 | 1 | 1.5384 | 0.0000 | 2 | U201.A17;J402.67
J402 | 68 | PL B35 | PL_B35_IO9_P | PL_B35_IO9_P | L19 | 35.3043 | 35.3043 | 33.7659 | 2 | 1.5384 | 0.0000 | 2 | U201.L19;J402.68
J402 | 69 | PS | PS_MIO22 | PS_MIO22 | B17 | 10.0895 | 10.0895 | 8.5511 | 1 | 1.5384 | 0.0000 | 2 | U201.B17;J402.69
J402 | 70 | PL B35 | PL_B35_IO9_N | PL_B35_IO9_N | L20 | 35.3043 | 35.3043 | 33.7659 | 2 | 1.5384 | 0.0000 | 2 | U201.L20;J402.70
J403 | 3 | PL B34 | PL_B34_IO7_N | PL_B34_IO7_N | Y17 | 38.7952 | 38.7952 | 37.2568 | 1 | 1.5384 | 0.0000 | 2 | U201.Y17;J403.3
J403 | 4 | PL B34 | PL_B34_IO16_N | PL_B34_IO16_N | W20 | 30.7718 | 30.7718 | 29.2334 | 1 | 1.5384 | 0.0000 | 2 | U201.W20;J403.4
J403 | 5 | PL B34 | PL_B34_IO7_P | PL_B34_IO7_P | Y16 | 38.7952 | 38.7952 | 37.2568 | 1 | 1.5384 | 0.0000 | 2 | U201.Y16;J403.5
J403 | 6 | PL B34 | PL_B34_IO16_P | PL_B34_IO16_P | V20 | 30.7718 | 30.7718 | 29.2334 | 1 | 1.5384 | 0.0000 | 2 | U201.V20;J403.6
J403 | 9 | PL B34 | PL_B34_IO17_N | PL_B34_IO17_N | Y19 | 38.1787 | 38.1787 | 36.6403 | 1 | 1.5384 | 0.0000 | 2 | U201.Y19;J403.9
J403 | 10 | PL B34 | PL_B34_IO15_N | PL_B34_IO15_N | U20 | 32.0038 | 32.0038 | 30.4654 | 1 | 1.5384 | 0.0000 | 2 | U201.U20;J403.10
J403 | 11 | PL B34 | PL_B34_IO17_P | PL_B34_IO17_P | Y18 | 38.0117 | 38.0117 | 36.4733 | 1 | 1.5384 | 0.0000 | 2 | U201.Y18;J403.11
J403 | 12 | PL B34 | PL_B34_IO15_P | PL_B34_IO15_P | T20 | 32.0038 | 32.0038 | 30.4654 | 1 | 1.5384 | 0.0000 | 2 | U201.T20;J403.12
J403 | 15 | PL B34 | PL_B34_IO1_N | PL_B34_IO1_N | T10 | 39.3649 | 39.3649 | 37.8265 | 2 | 1.5384 | 0.0000 | 2 | U201.T10;J403.15
J403 | 16 | PL B34 | PL_B34_IO3_P | PL_B34_IO3_P | U13 | 22.6339 | 22.6339 | 21.0955 | 1 | 1.5384 | 0.0000 | 2 | U201.U13;J403.16
J403 | 17 | PL B34 | PL_B34_IO1_P | PL_B34_IO1_P | T11 | 39.4928 | 39.4928 | 37.9544 | 2 | 1.5384 | 0.0000 | 2 | U201.T11;J403.17
J403 | 18 | PL B34 | PL_B34_IO3_N | PL_B34_IO3_N | V13 | 22.4925 | 22.4925 | 20.9541 | 1 | 1.5384 | 0.0000 | 2 | U201.V13;J403.18
J403 | 21 | PL B34 | PL_B34_IO2_N | PL_B34_IO2_N | U12 | 40.0834 | 40.0834 | 38.5450 | 2 | 1.5384 | 0.0000 | 2 | U201.U12;J403.21
J403 | 22 | PL B34 | PL_B34_IO8_P | PL_B34_IO8_P | W14 | 20.0018 | 20.0018 | 18.4634 | 1 | 1.5384 | 0.0000 | 2 | U201.W14;J403.22
J403 | 23 | PL B34 | PL_B34_IO2_P | PL_B34_IO2_P | T12 | 40.0834 | 40.0834 | 38.5450 | 2 | 1.5384 | 0.0000 | 2 | U201.T12;J403.23
J403 | 24 | PL B34 | PL_B34_IO8_N | PL_B34_IO8_N | Y14 | 19.9867 | 19.9867 | 18.4483 | 1 | 1.5384 | 0.0000 | 2 | U201.Y14;J403.24
J403 | 27 | PL B34 | PL_B34_IO4_P | PL_B34_IO4_P | V12 | 39.3740 | 39.3740 | 37.7116 | 2 | 1.6624 | 0.0000 | 2 | U201.V12;J403.27
J403 | 28 | PL B34 | PL_B34_IO11_P | PL_B34_IO11_P | U14 | 22.4945 | 22.4945 | 20.9561 | 1 | 1.5384 | 0.0000 | 2 | U201.U14;J403.28
J403 | 29 | PL B34 | PL_B34_IO4_N | PL_B34_IO4_N | W13 | 39.3825 | 39.3825 | 37.7201 | 2 | 1.6624 | 0.0000 | 2 | U201.W13;J403.29
J403 | 30 | PL B34 | PL_B34_IO11_N | PL_B34_IO11_N | U15 | 22.3716 | 22.3716 | 20.8332 | 1 | 1.5384 | 0.0000 | 2 | U201.U15;J403.30
J403 | 33 | PL B34 | PL_B34_IO9_P | PL_B34_IO9_P | T16 | 44.8547 | 44.8547 | 43.1923 | 2 | 1.6624 | 0.0000 | 2 | U201.T16;J403.33
J403 | 34 | PL B34 | PL_B34_IO5_P | PL_B34_IO5_P | T14 | 18.9993 | 18.9993 | 17.4609 | 2 | 1.5384 | 0.0000 | 2 | U201.T14;J403.34
J403 | 35 | PL B34 | PL_B34_IO9_N | PL_B34_IO9_N | U17 | 44.8461 | 44.8461 | 43.1837 | 2 | 1.6624 | 0.0000 | 2 | U201.U17;J403.35
J403 | 36 | PL B34 | PL_B34_IO5_N | PL_B34_IO5_N | T15 | 18.9993 | 18.9993 | 17.4609 | 2 | 1.5384 | 0.0000 | 2 | U201.T15;J403.36
J403 | 39 | PL B34 | PL_B34_IO20_P | PL_B34_IO20_P | T17 | 38.1690 | 38.1690 | 36.6306 | 2 | 1.5384 | 0.0000 | 2 | U201.T17;J403.39
J403 | 40 | PL B34 | PL_B34_IO14_P | PL_B34_IO14_P | N20 | 38.0472 | 38.0472 | 36.5089 | 1 | 1.5384 | 0.0000 | 2 | U201.N20;J403.40
J403 | 41 | PL B34 | PL_B34_IO20_N | PL_B34_IO20_N | R18 | 38.1457 | 38.1457 | 36.6073 | 2 | 1.5384 | 0.0000 | 2 | U201.R18;J403.41
J403 | 42 | PL B34 | PL_B34_IO14_N | PL_B34_IO14_N | P20 | 38.0473 | 38.0473 | 36.5089 | 1 | 1.5384 | 0.0000 | 2 | U201.P20;J403.42
J403 | 45 | PL B34 | PL_B34_IO21_P | PL_B34_IO21_P | V17 | 31.8645 | 31.8645 | 30.3261 | 2 | 1.5384 | 0.0000 | 2 | U201.V17;J403.45
J403 | 46 | PL B34 | PL_B34_IO13_P | PL_B34_IO13_P | N18 | 29.8043 | 29.8043 | 28.2659 | 1 | 1.5384 | 0.0000 | 2 | U201.N18;J403.46
J403 | 47 | PL B34 | PL_B34_IO21_N | PL_B34_IO21_N | V18 | 32.0632 | 32.0632 | 30.5248 | 2 | 1.5384 | 0.0000 | 2 | U201.V18;J403.47
J403 | 48 | PL B34 | PL_B34_IO13_N | PL_B34_IO13_N | P19 | 29.7957 | 29.7957 | 28.2573 | 1 | 1.5384 | 0.0000 | 2 | U201.P19;J403.48
J403 | 51 | PL B34 | PL_B34_IO12_N | PL_B34_IO12_N | U19 | 31.8816 | 31.8816 | 30.3432 | 2 | 1.5384 | 0.0000 | 2 | U201.U19;J403.51
J403 | 52 | PL B34 | PL_B34_IO22_P | PL_B34_IO22_P | W18 | 16.7702 | 16.7702 | 15.2318 | 1 | 1.5384 | 0.0000 | 2 | U201.W18;J403.52
J403 | 53 | PL B34 | PL_B34_IO12_P | PL_B34_IO12_P | U18 | 32.0802 | 32.0802 | 30.5418 | 2 | 1.5384 | 0.0000 | 2 | U201.U18;J403.53
J403 | 54 | PL B34 | PL_B34_IO22_N | PL_B34_IO22_N | W19 | 16.7702 | 16.7702 | 15.2318 | 1 | 1.5384 | 0.0000 | 2 | U201.W19;J403.54
J403 | 57 | PL B34 | PL_B34_IO19_N | PL_B34_IO19_N | R17 | 32.3187 | 32.3187 | 30.7803 | 2 | 1.5384 | 0.0000 | 2 | U201.R17;J403.57
J403 | 58 | PL B34 | PL_B34_IO10_N | PL_B34_IO10_N | W15 | 19.5445 | 19.5445 | 18.0061 | 2 | 1.5384 | 0.0000 | 2 | U201.W15;J403.58
J403 | 59 | PL B34 | PL_B34_IO19_P | PL_B34_IO19_P | R16 | 32.3187 | 32.3187 | 30.7803 | 2 | 1.5384 | 0.0000 | 2 | U201.R16;J403.59
J403 | 60 | PL B34 | PL_B34_IO10_P | PL_B34_IO10_P | V15 | 19.5445 | 19.5445 | 18.0061 | 2 | 1.5384 | 0.0000 | 2 | U201.V15;J403.60
J403 | 63 | PL B34 | PL_B34_IO23_N | PL_B34_IO23_N | P18 | 32.3217 | 32.3217 | 30.7833 | 2 | 1.5384 | 0.0000 | 2 | U201.P18;J403.63
J403 | 64 | PL B34 | PL_B34_IO18_P | PL_B34_IO18_P | V16 | 18.8678 | 18.8678 | 17.3294 | 2 | 1.5384 | 0.0000 | 2 | U201.V16;J403.64
J403 | 65 | PL B34 | PL_B34_IO23_P | PL_B34_IO23_P | N17 | 32.3132 | 32.3132 | 30.7748 | 2 | 1.5384 | 0.0000 | 2 | U201.N17;J403.65
J403 | 66 | PL B34 | PL_B34_IO18_N | PL_B34_IO18_N | W16 | 18.9842 | 18.9842 | 17.4458 | 2 | 1.5384 | 0.0000 | 2 | U201.W16;J403.66

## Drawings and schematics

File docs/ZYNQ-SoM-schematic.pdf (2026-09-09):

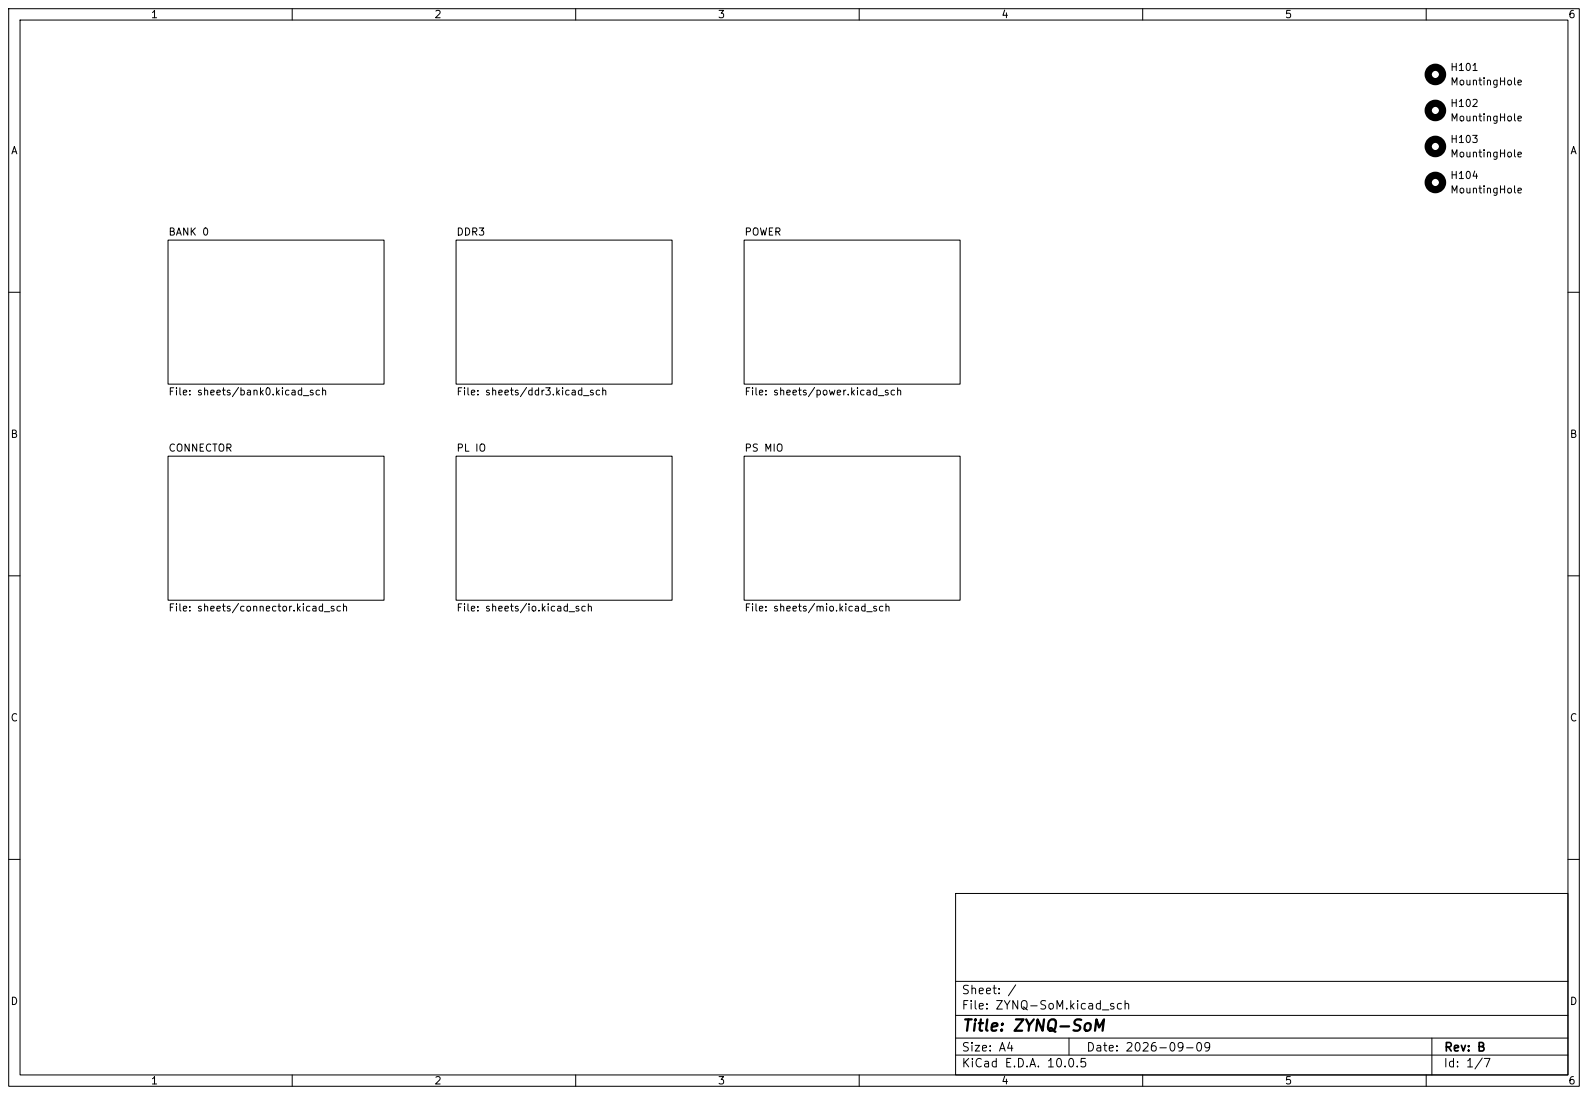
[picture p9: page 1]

File: sheets/mio.kicad_sch POWER

File: sheets/ddr3.kicad_sch PL IO

Size: A4 | Rev: B
KiCad E.D.A. 10.0.5 | Id: 1/7

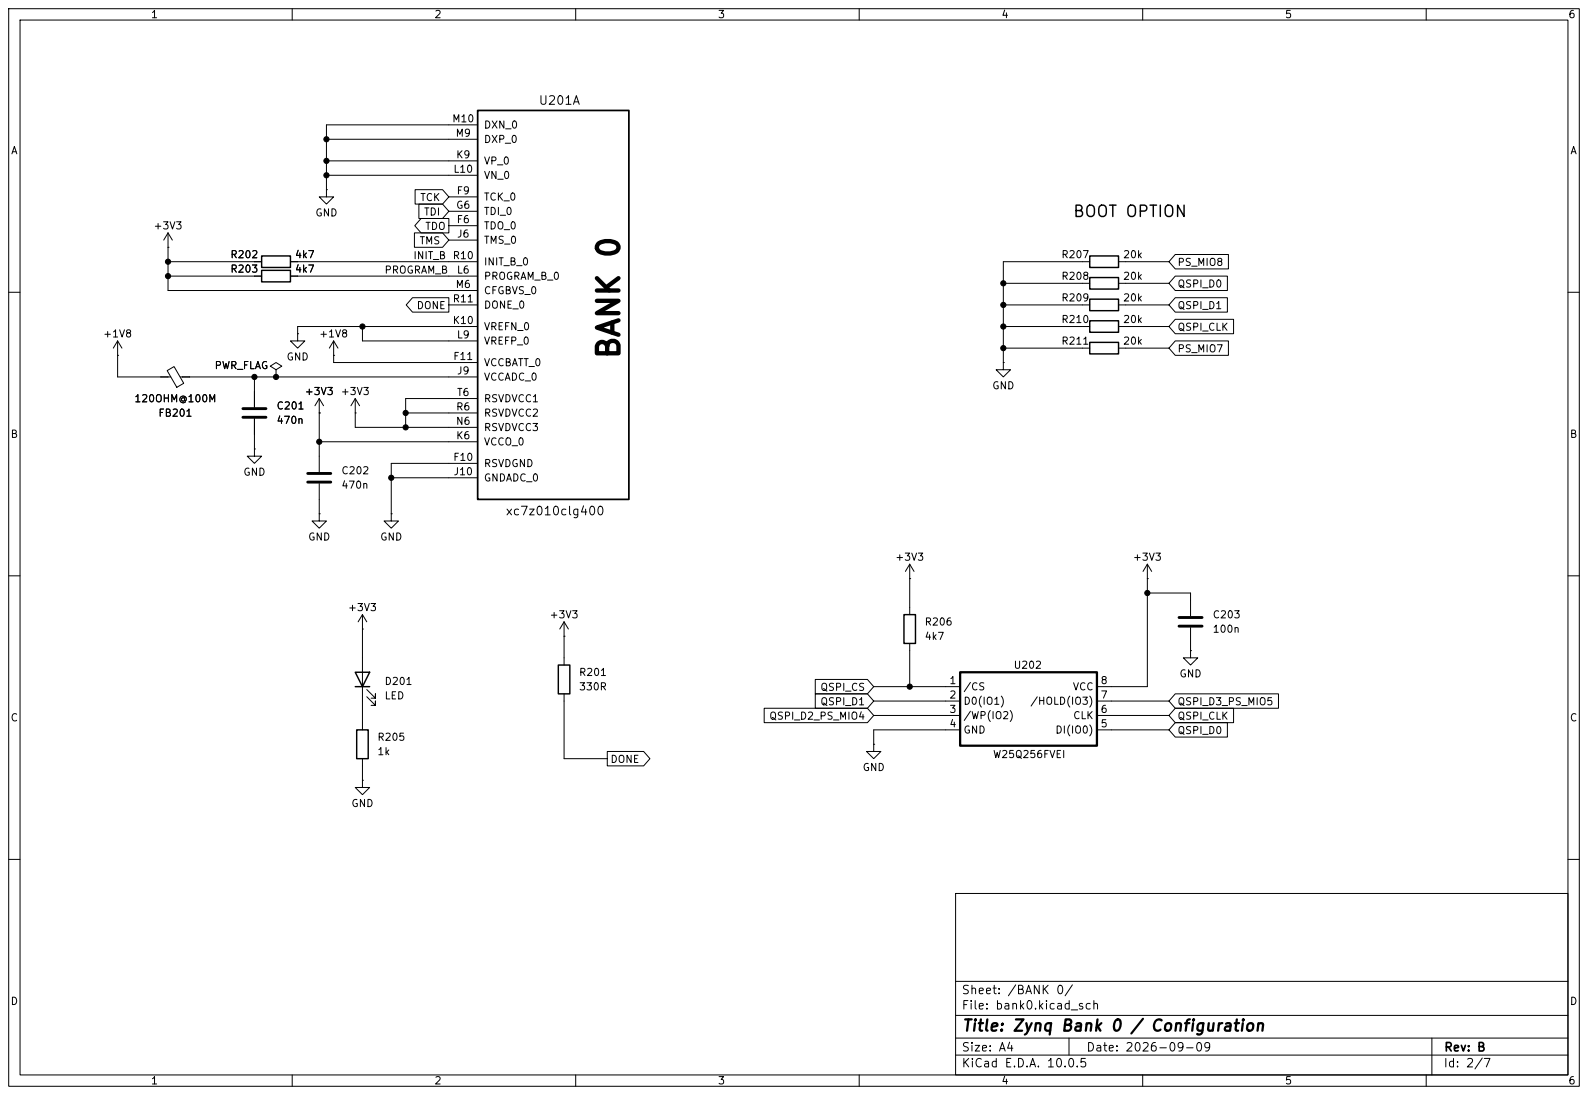
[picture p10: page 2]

Sheet: /BANK 0/
File: bank0.kicad_sch
Title: Zynq Bank 0 / Configuration

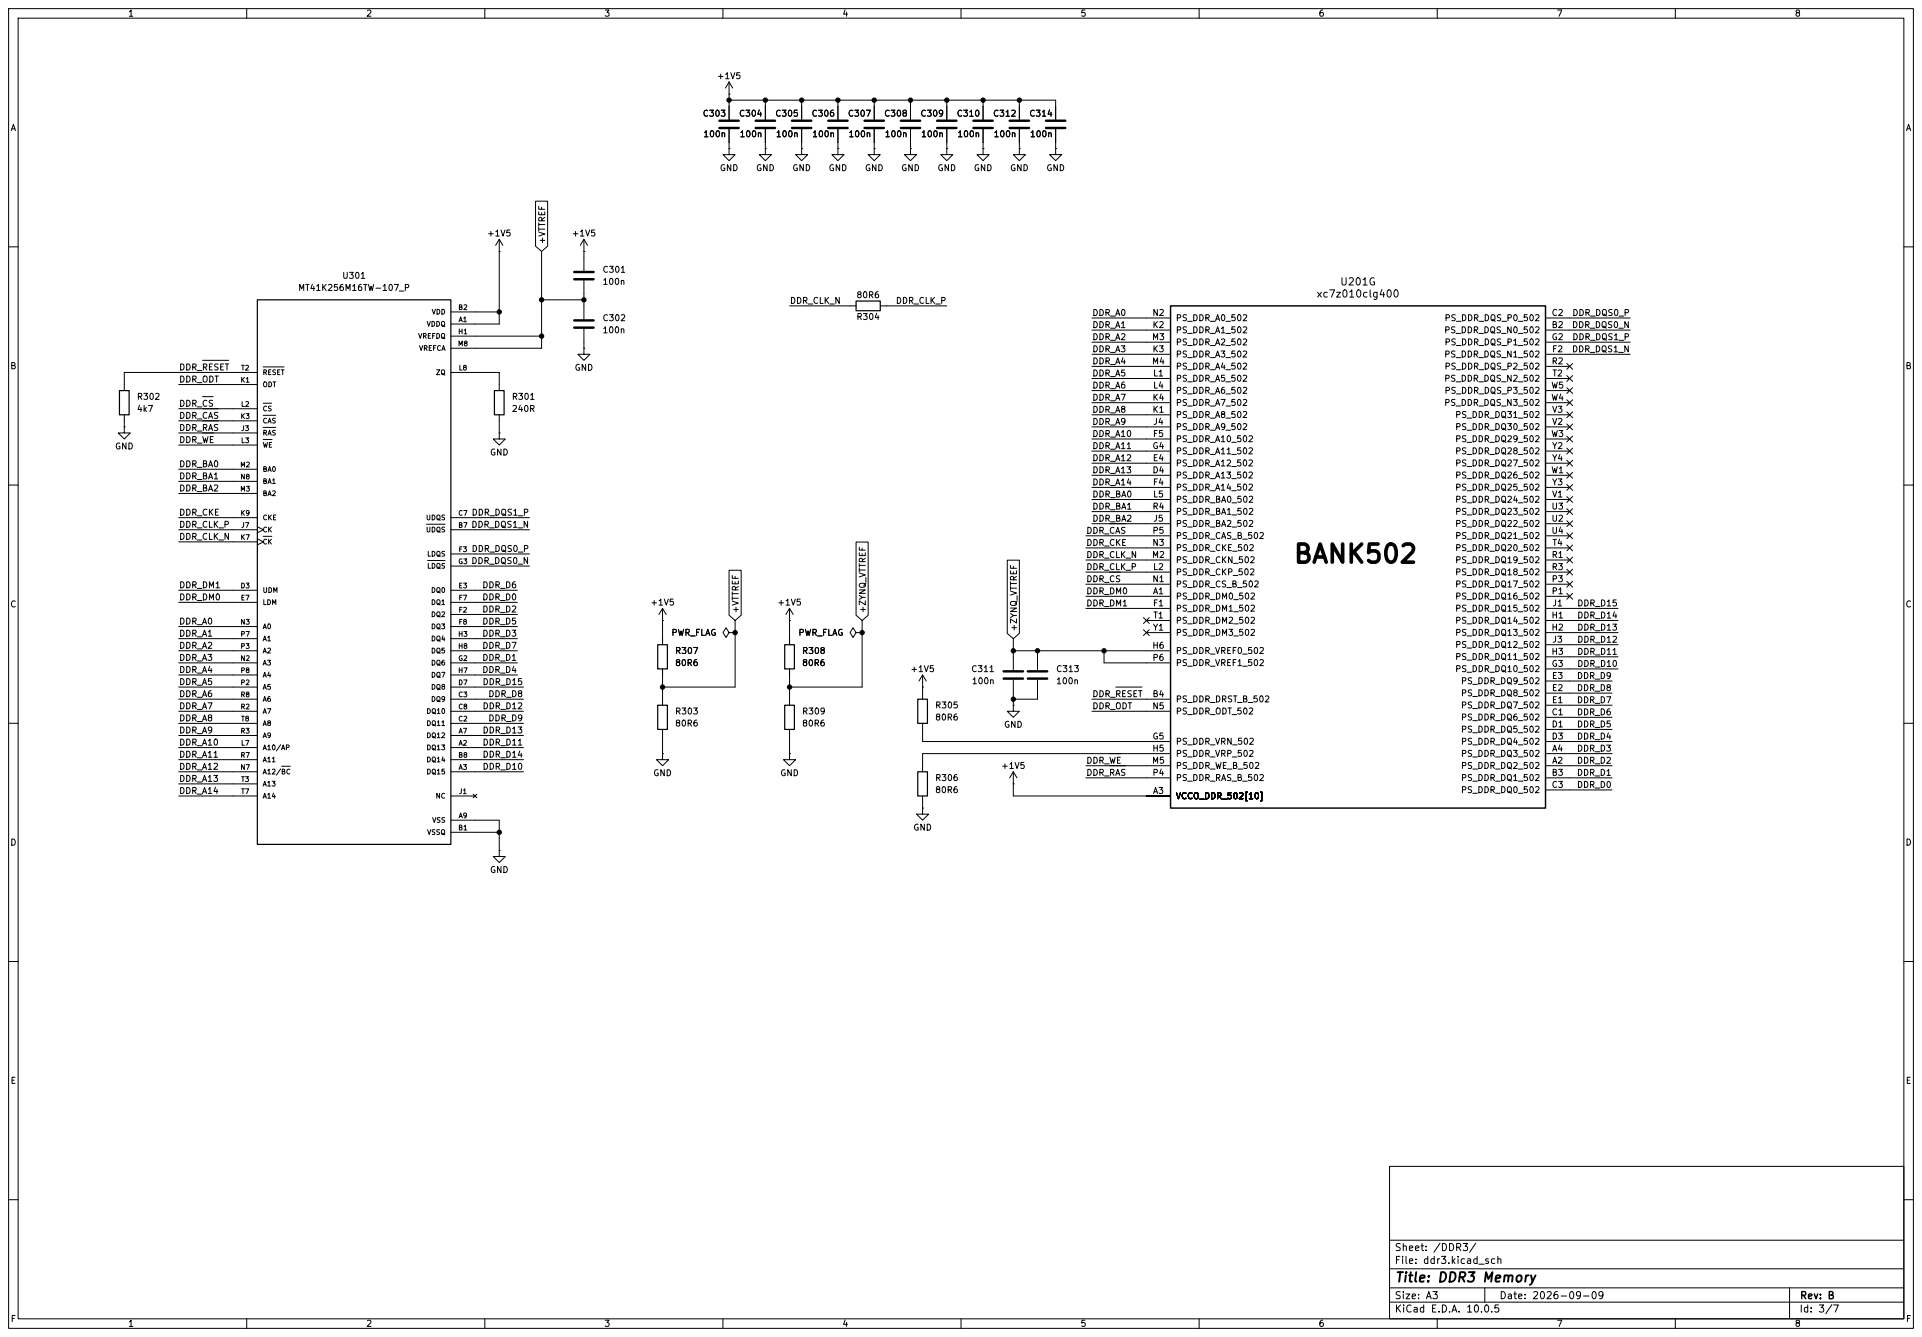
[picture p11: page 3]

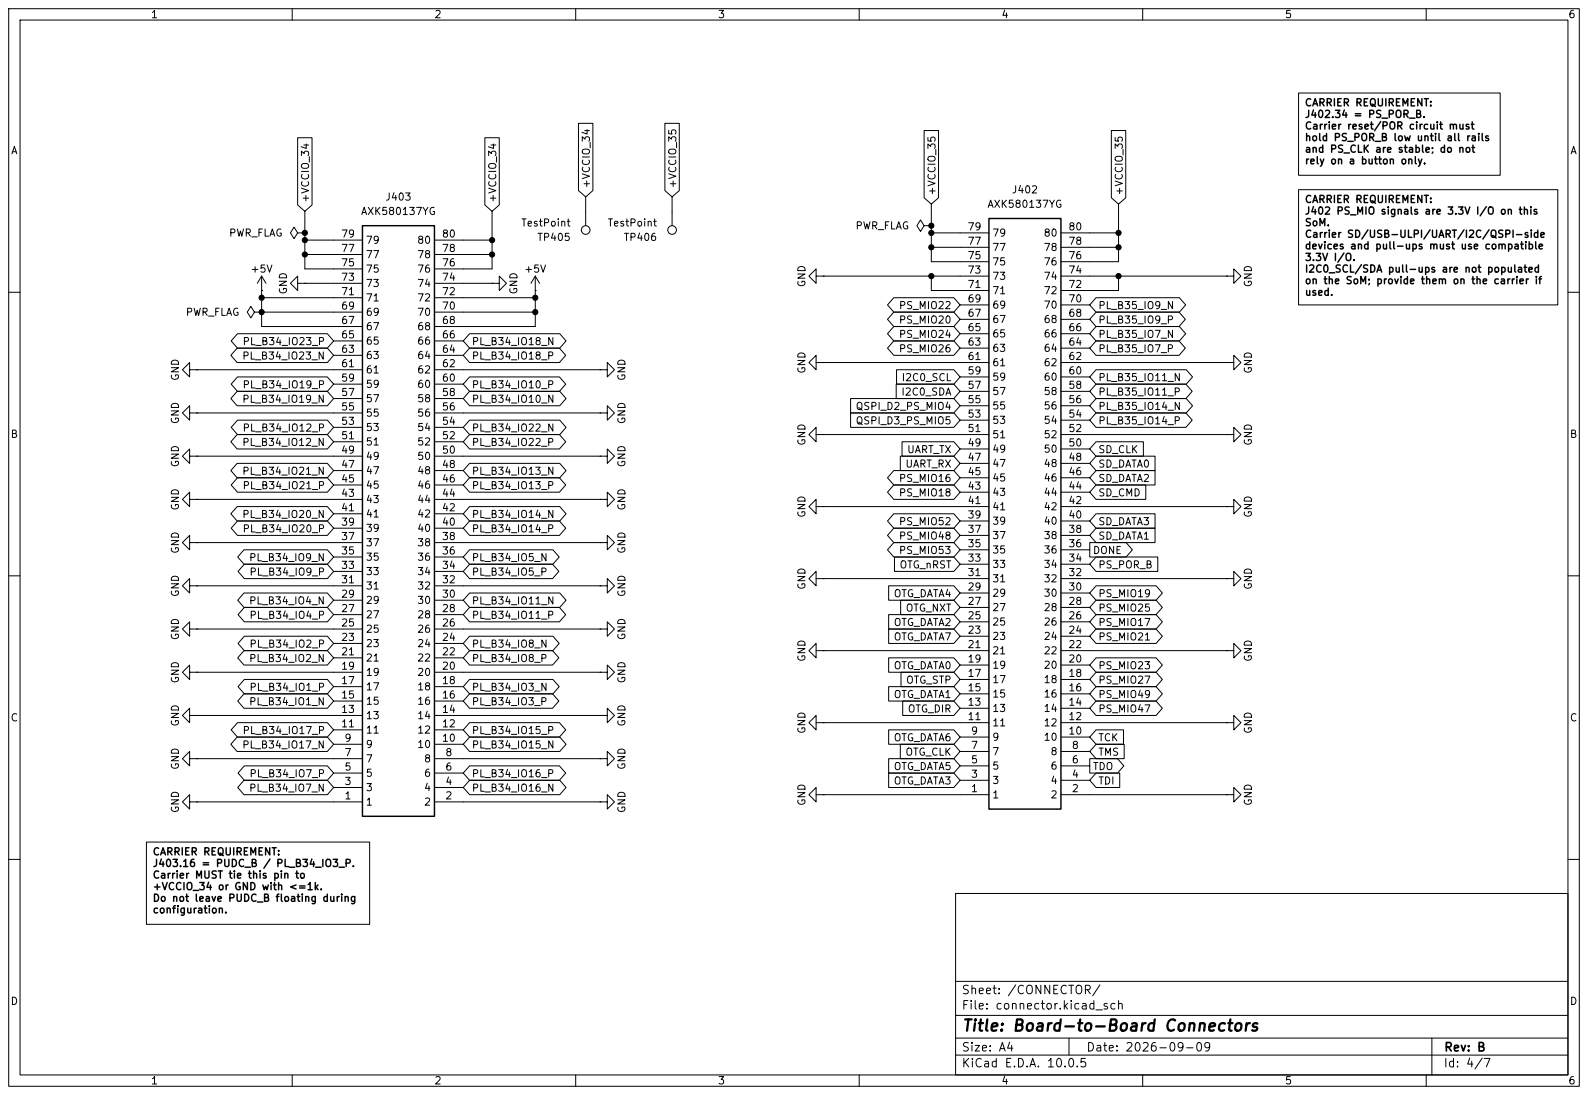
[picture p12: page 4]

CARRIER REQUIREMENT: J402.34 = PS_POR_B. Carrier reset/POR circuit must hold PS_POR_B low until all rails and PS_CLK are stable; do not rely on a button only. CARRIER REQUIREMENT: J402 PS_MIO signals are 3.3V I/O on this SoM. Carrier SD/USB-ULPI/UART/I2C/QSPI-side devices and pull-ups must use compatible 3.3V I/O.

I2C0_SCL/SDA pull-ups are not populated

on the SoM; provide them on the carrier if used. CARRIER REQUIREMENT: J403.16 = PUDC_B / PL_B34_IO3_P. Carrier MUST tie this pin to +VCCIO_34 or GND with <=1k. Do not leave PUDC_B floating during

File: connector.kicad_sch
Title: Board-to-Board Connectors

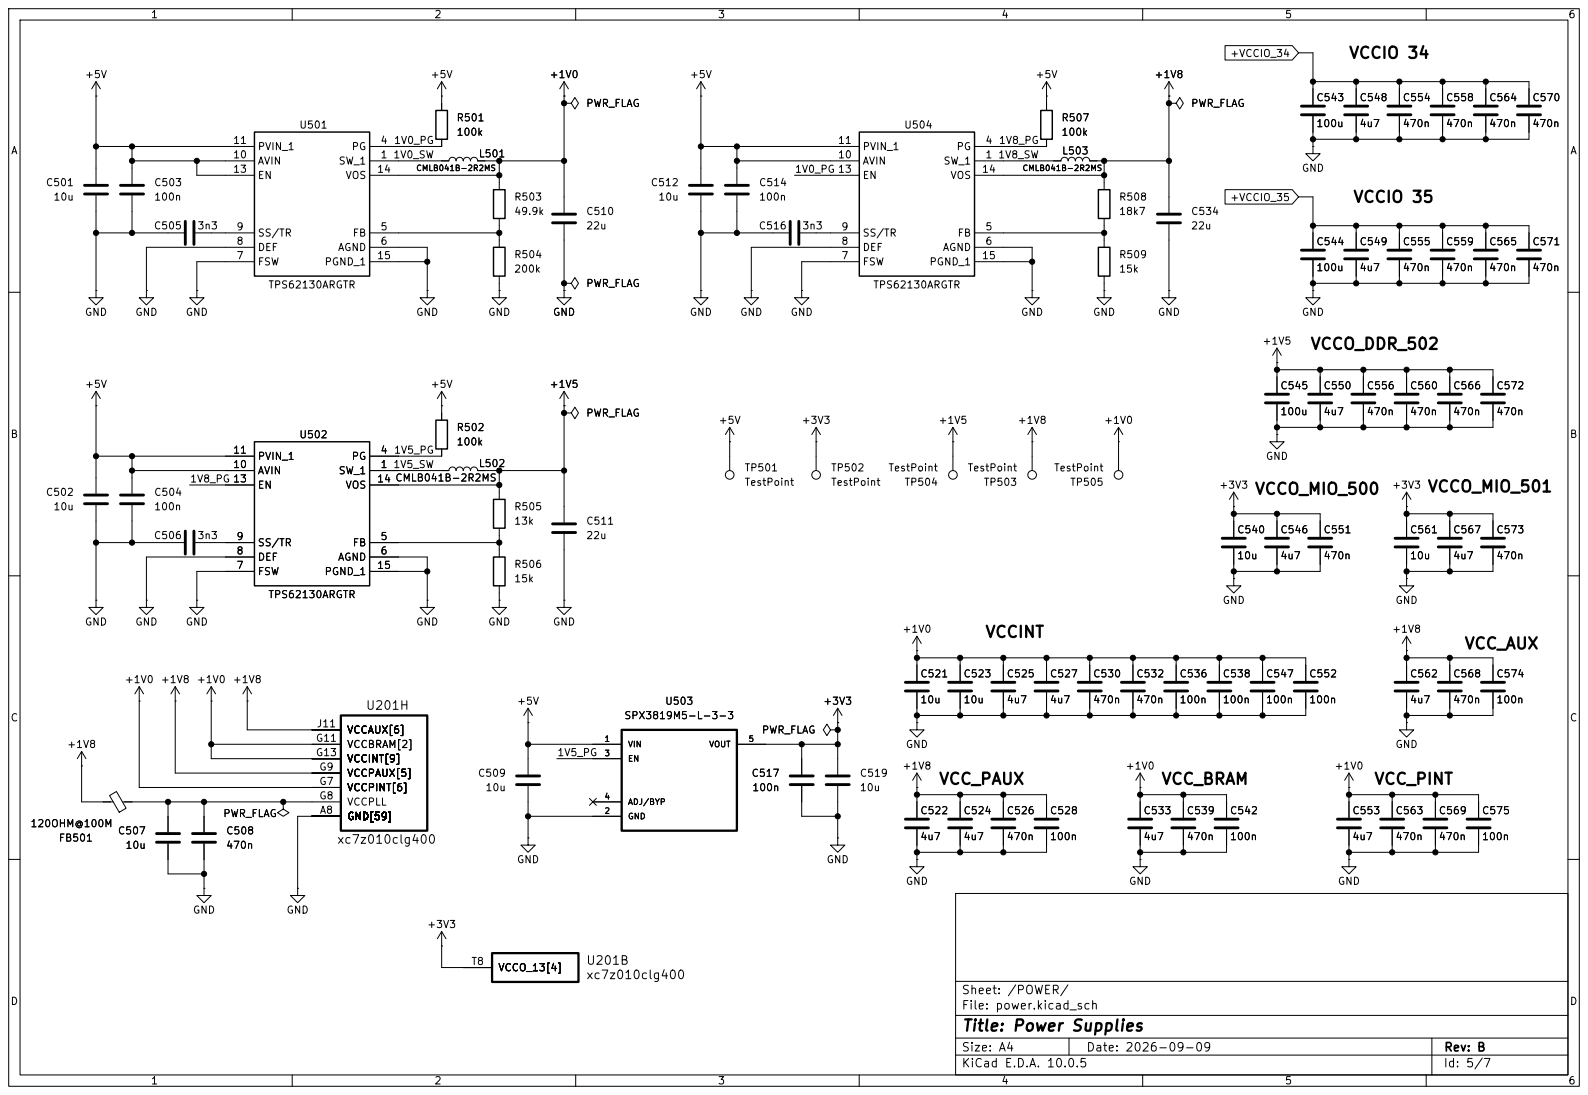
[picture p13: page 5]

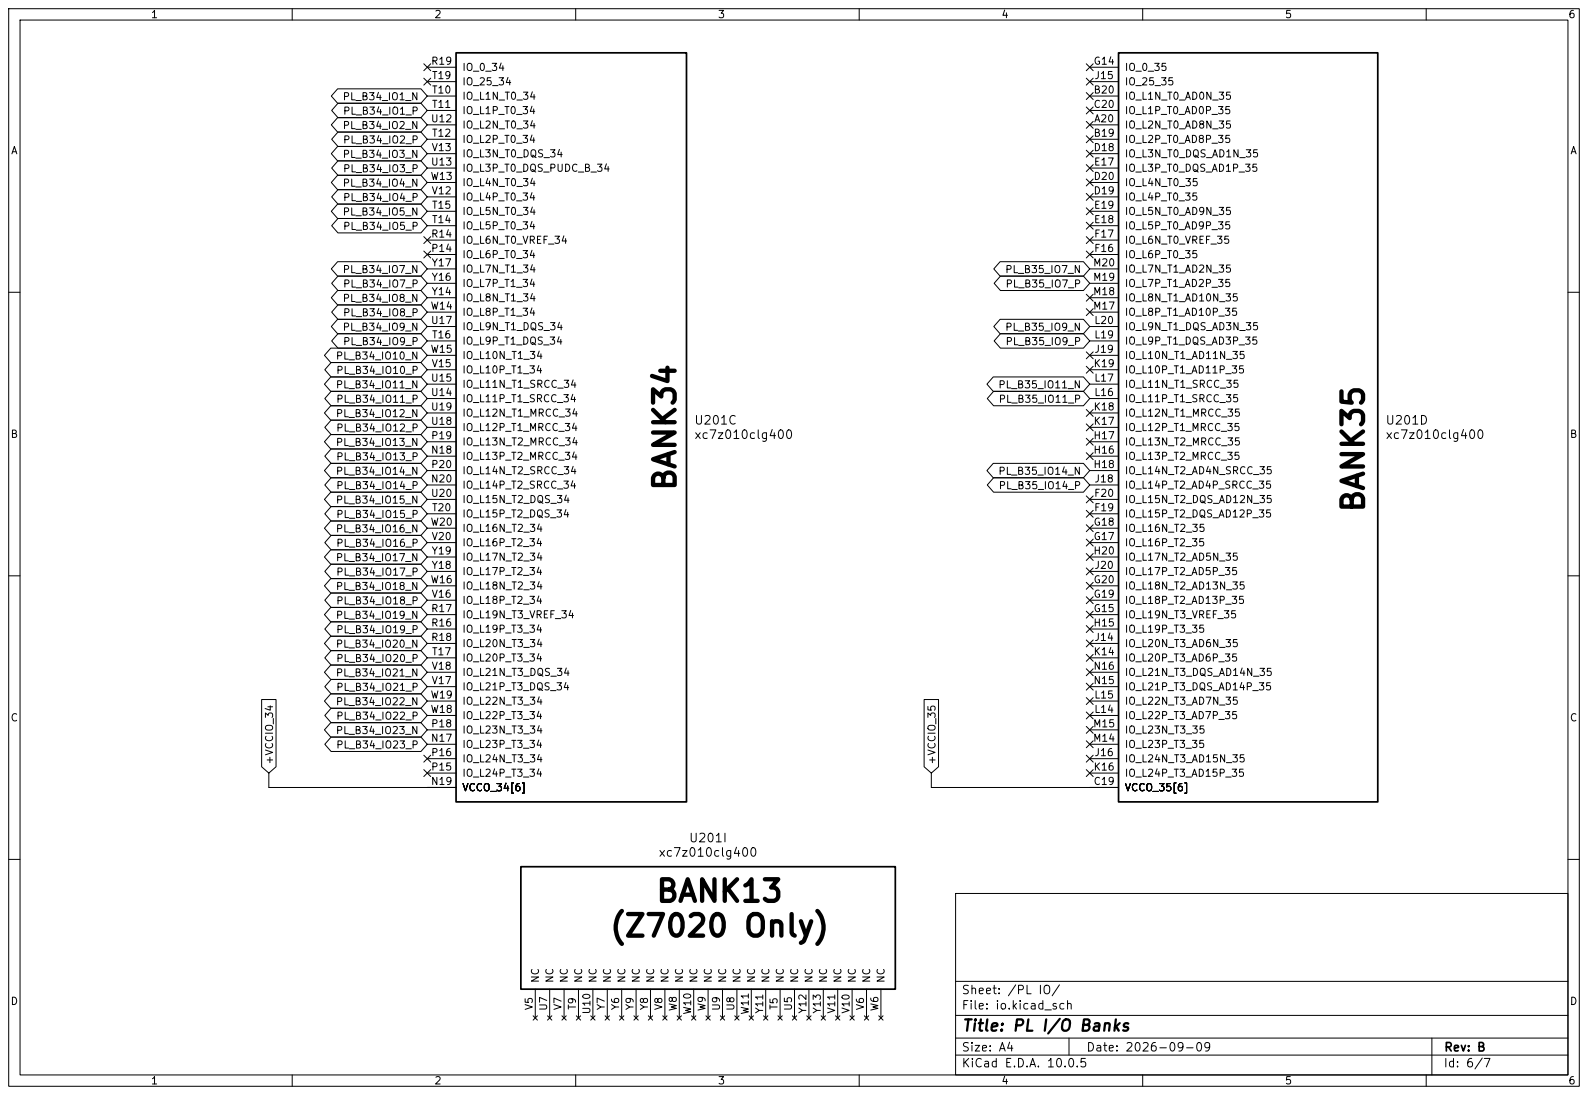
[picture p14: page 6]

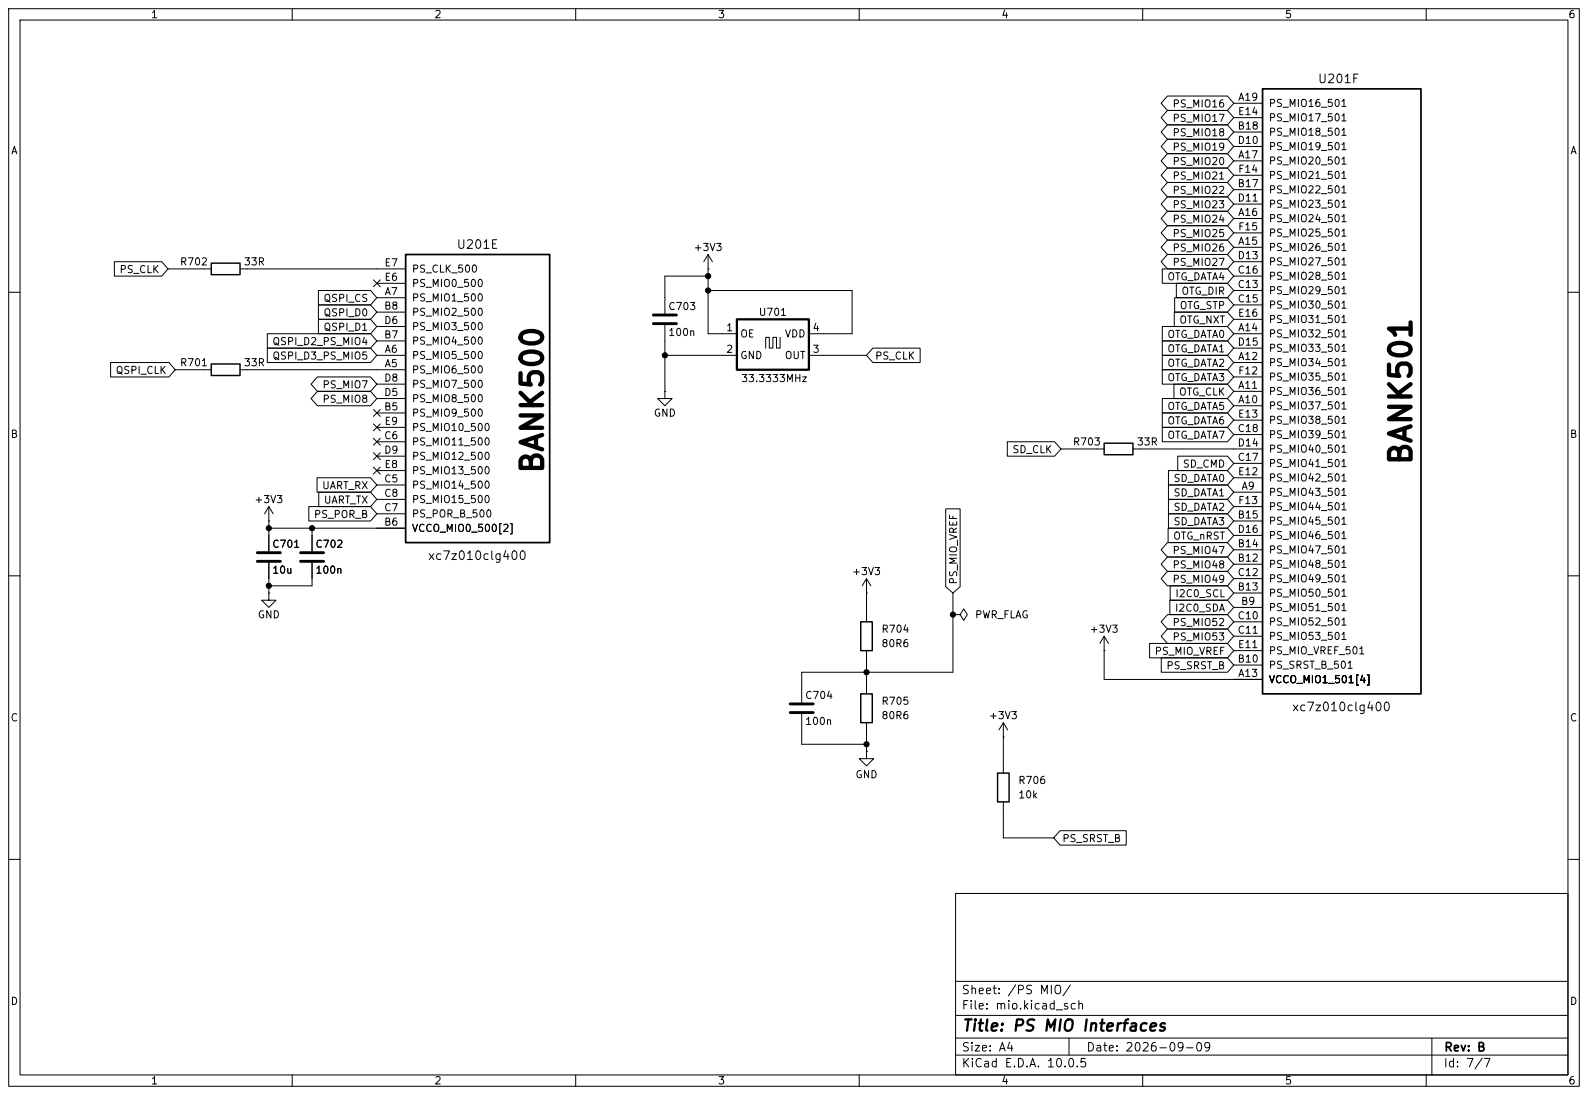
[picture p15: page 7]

File: mio.kicad_sch
Title: PS MIO Interfaces

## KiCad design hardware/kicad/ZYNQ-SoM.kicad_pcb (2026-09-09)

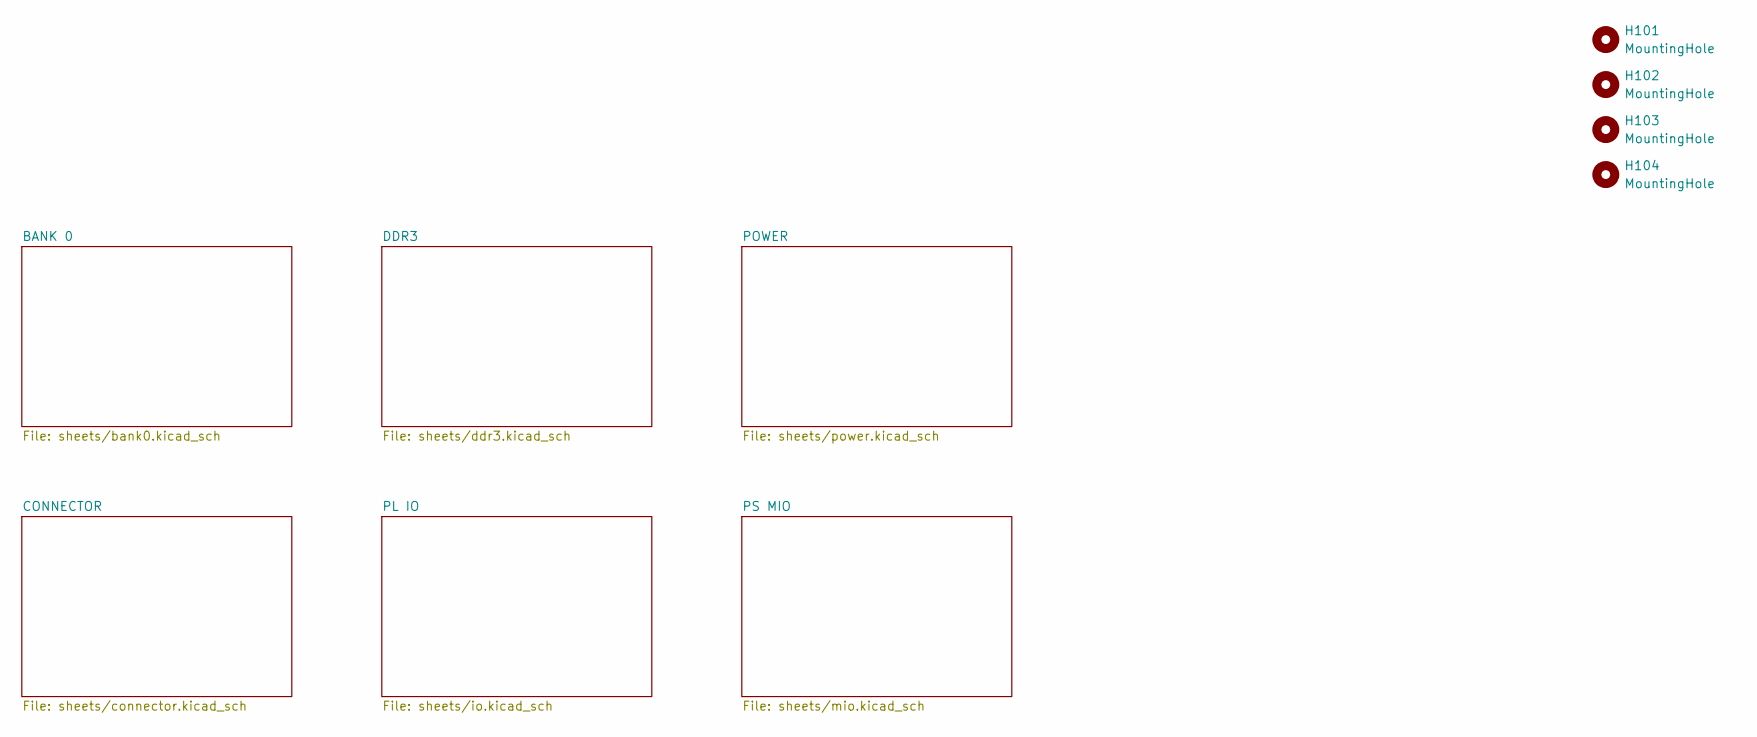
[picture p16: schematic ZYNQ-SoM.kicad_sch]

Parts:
H101, H102, H103, H104: MountingHole; MountingHole_2.2mm_M2

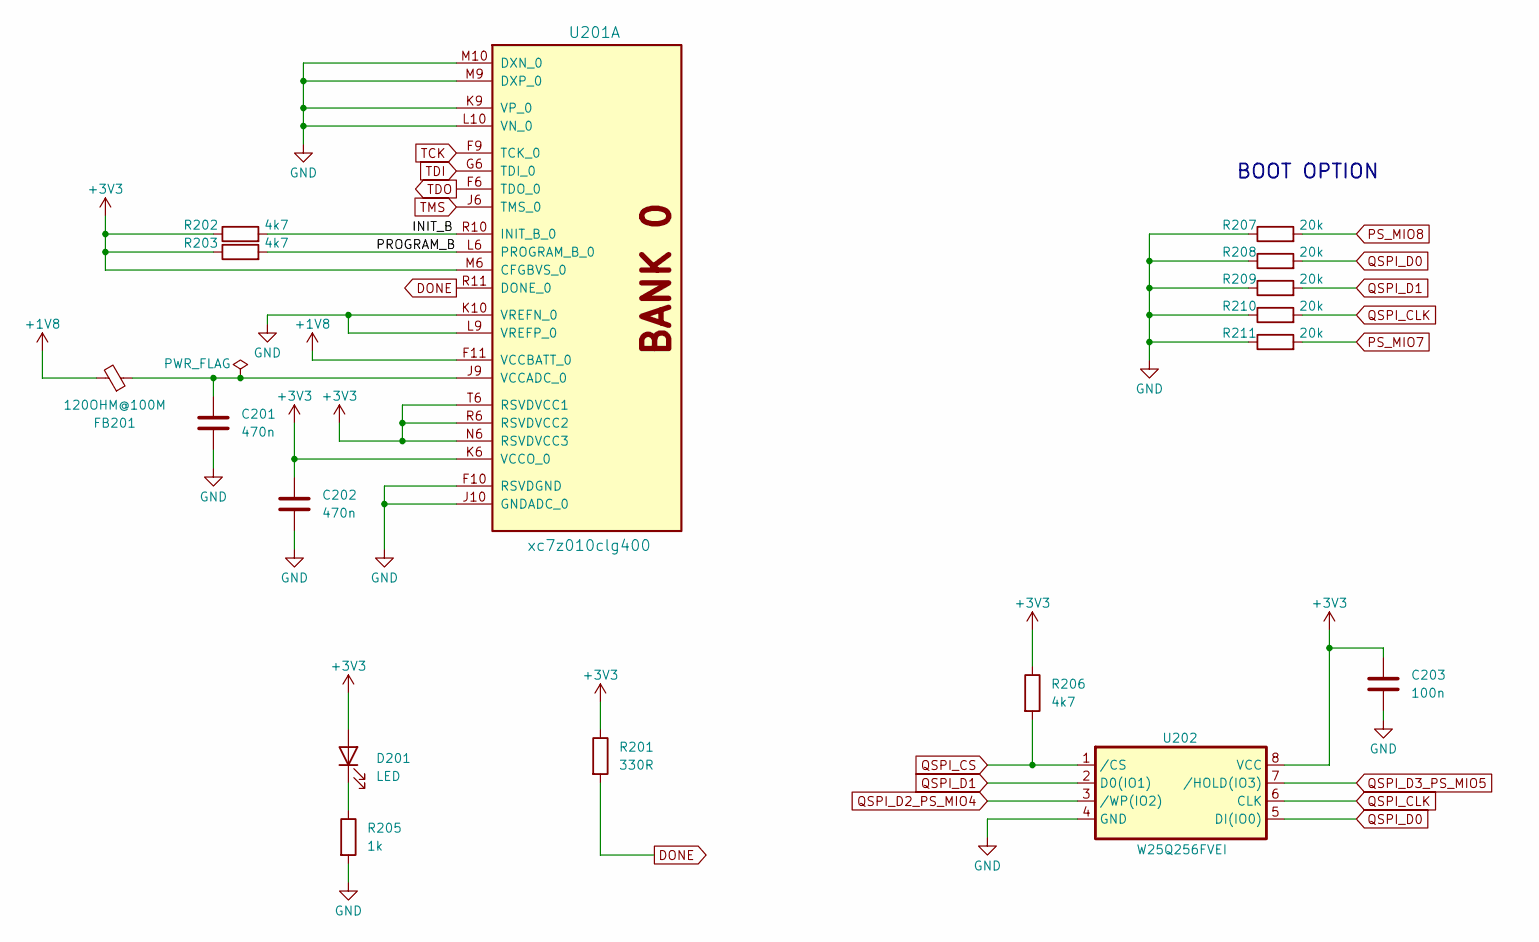
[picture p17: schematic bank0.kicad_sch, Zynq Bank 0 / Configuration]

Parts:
C201, C202: 470n; C_0402_1005Metric
C203: 100n; C_0402_1005Metric
D201: LED; LED_0603_1608Metric
FB201: 120OHM@100M; L_0402_1005Metric
R201: 330R; R_0402_1005Metric
R202, R203, R206: 4k7; R_0402_1005Metric
R205: 1k; R_0402_1005Metric
R207, R208, R209, R210, R211: 20k; R_0402_1005Metric
U201: xc7z010clg400; Xilinx_CLG400
U202: W25Q256FVEI; SON127P800X600X80-9N-D

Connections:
+1V8: FB201.2, U201.F11 (VCCBATT_0); also elsewhere on the board
+3V3: C202.1, C203.1, D201.2 (A), R201.1, R202.1, R203.1, R206.1, U201.K6 (VCCO_0), U201.M6 (CFGBVS_0), U201.N6 (RSVDVCC3), U201.R6 (RSVDVCC2), U201.T6 (RSVDVCC1), U202.8 (VCC); also elsewhere on the board
/BANK 0/INIT_B: R202.2, U201.R10 (INIT_B_0)
/BANK 0/PROGRAM_B: R203.2, U201.L6 (PROGRAM_B_0)
DONE: R201.2, U201.R11 (DONE_0); also elsewhere on the board
GND: C201.2, C202.2, C203.2, R205.2, R207.1, R208.1, R209.1, R210.1, R211.1, U201.F10 (RSVDGND), U201.J10 (GNDADC_0), U201.K9 (VP_0), U201.K10 (VREFN_0), U201.L9 (VREFP_0), U201.L10 (VN_0), U201.M9 (DXP_0), U201.M10 (DXN_0), U202.4 (GND), U202.9 (GND); also elsewhere on the board
unnamed: D201.1 (K), R205.1
unnamed: C201.1, FB201.1, U201.J9 (VCCADC_0)
PS_MIO7: R211.2; also elsewhere on the board
PS_MIO8: R207.2; also elsewhere on the board
QSPI_CLK: R210.2, U202.6 (CLK); also elsewhere on the board
QSPI_CS: R206.2, U202.1 (/CS); also elsewhere on the board
QSPI_D0: R208.2, U202.5 (DI(IO0)); also elsewhere on the board
QSPI_D1: R209.2, U202.2 (D0(IO1)); also elsewhere on the board
QSPI_D2_PS_MIO4: U202.3 (/WP(IO2)); also elsewhere on the board
QSPI_D3_PS_MIO5: U202.7 (/HOLD(IO3)); also elsewhere on the board
TCK: U201.F9 (TCK_0); also elsewhere on the board
TDI: U201.G6 (TDI_0); also elsewhere on the board
TDO: U201.F6 (TDO_0); also elsewhere on the board
TMS: U201.J6 (TMS_0); also elsewhere on the board

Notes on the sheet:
BOOT OPTION

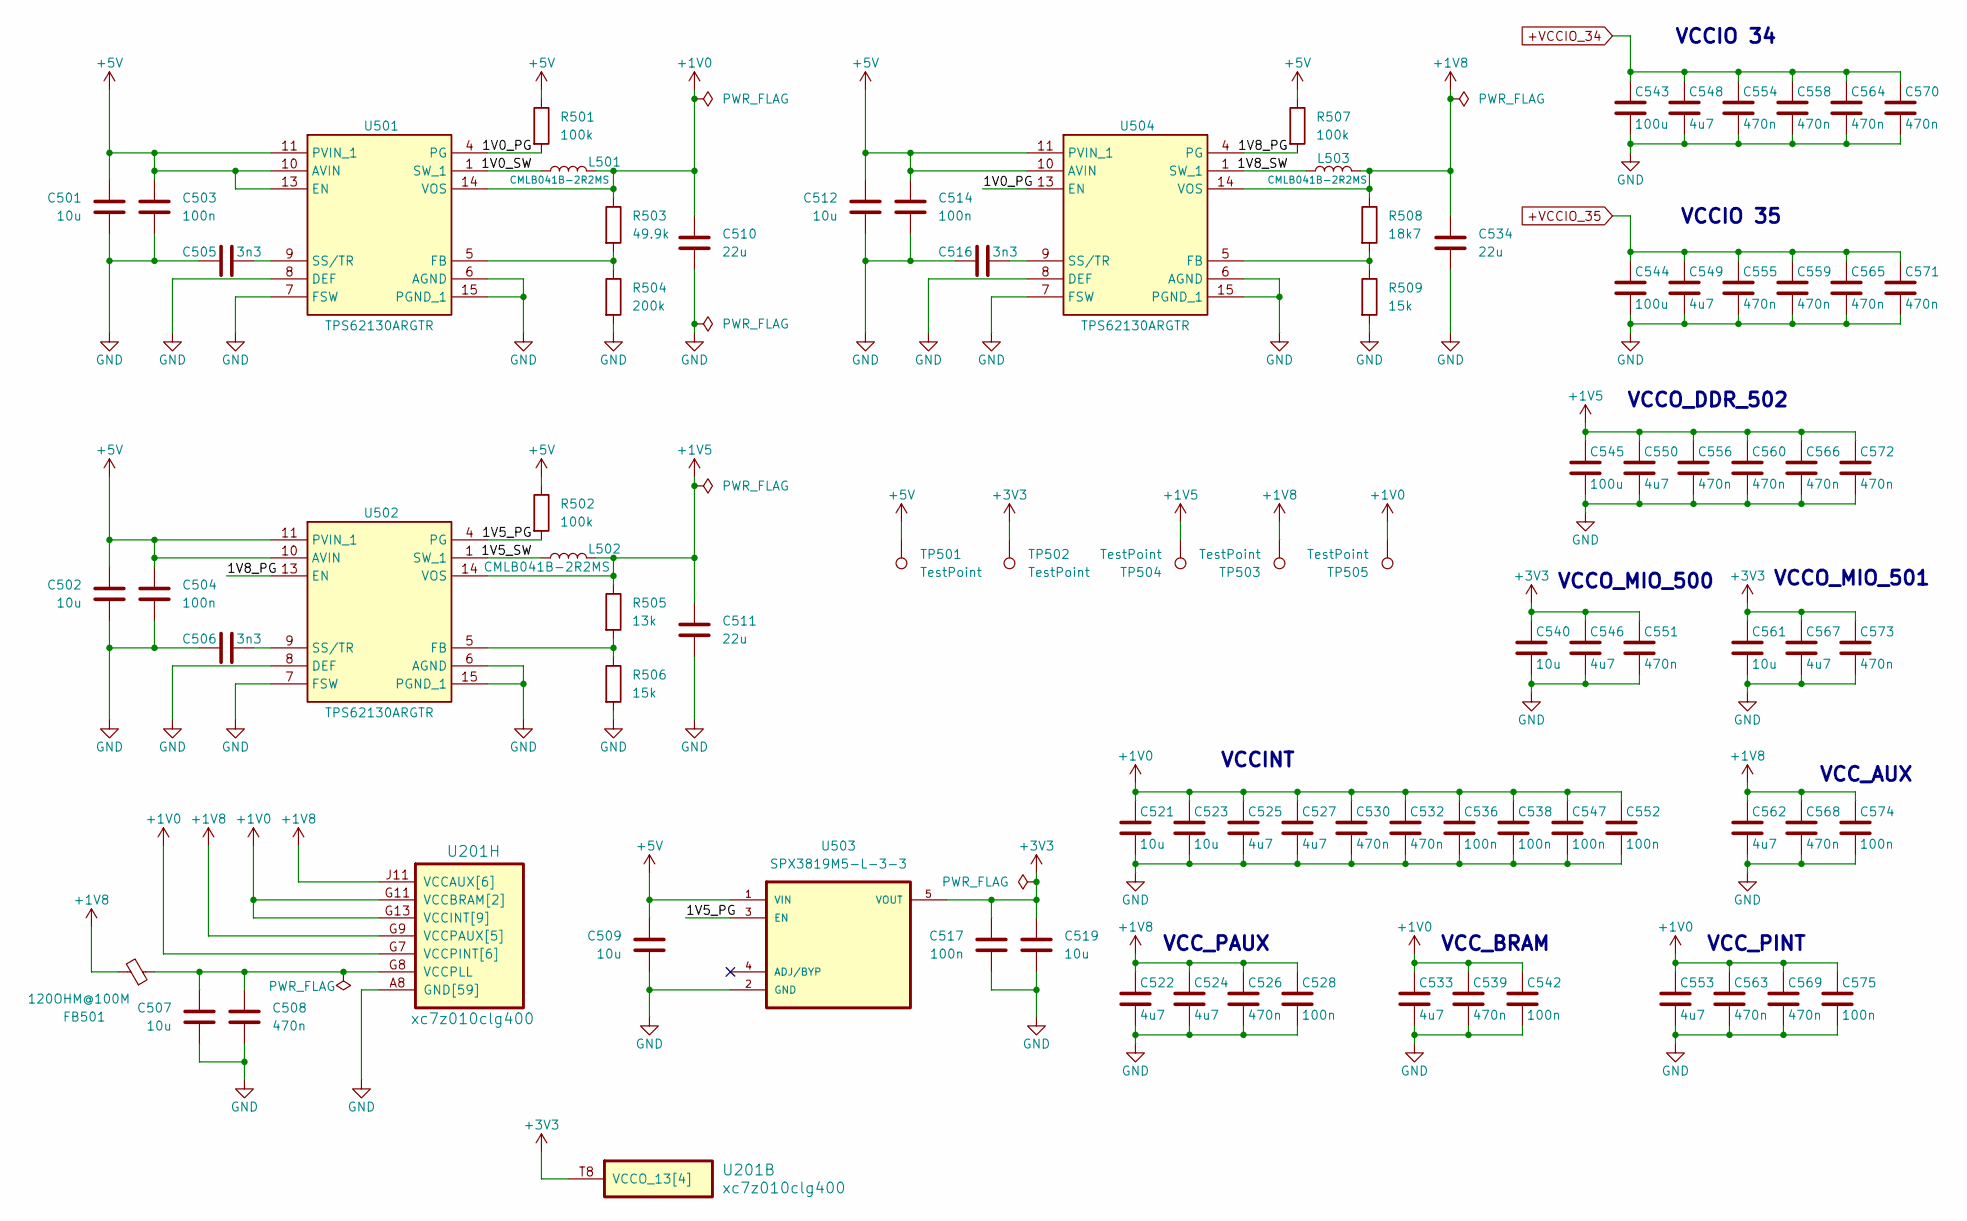
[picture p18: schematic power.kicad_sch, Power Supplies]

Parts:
C501, C502, C509, C512, C519, C521, C523, C561: 10u; C_0805_2012Metric
C503, C504, C514, C517, C528, C536, C538, C542, C547, C552, C574, C575: 100n; C_0402_1005Metric
C505, C506, C516: 3n3; C_0402_1005Metric
C507, C540: 10u; C_0603_1608Metric
C508, C526, C530, C532, C539, C551, C554, C555, C556, C558, C559, C560, C563, C564, C565, C566, C568, C569, C570, C571, C572, C573: 470n; C_0402_1005Metric
C510, C511, C534: 22u; C_0805_2012Metric
C522, C524, C525, C527, C533, C546, C548, C549, C550, C553, C562, C567: 4u7; C_0603_1608Metric
C543, C544, C545: 100u; C_1206_3216Metric
FB501: 120OHM@100M; L_0402_1005Metric
L501, L502, L503: CMLB041B-2R2MS; IND_CMLB041B-1R0MS
R501, R502, R507: 100k; R_0402_1005Metric
R503: 49.9k; R_0402_1005Metric
R504: 200k; R_0402_1005Metric
R505: 13k; R_0402_1005Metric
R506, R509: 15k; R_0402_1005Metric
R508: 18k7; R_0402_1005Metric
TP501, TP502, TP503, TP504, TP505: TestPoint; TestPoint_Pad_D1.0mm
U201: xc7z010clg400; Xilinx_CLG400
U501, U502, U504: TPS62130ARGTR; QFN50P300X300X100-17N-D; Manufacturer_Part_Number TPS62130ARGTR; Mouser Part Number 595-TPS62130ARGTR
U503: SPX3819M5-L-3-3; MPN SPX3819M5-L-3-3

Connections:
+1V0: C510.1, C521.1, C523.1, C525.1, C527.1, C530.1, C532.1, C533.1, C536.1, C538.1, C539.1, C542.1, C547.1, C552.1, C553.1, C563.1, C569.1, C575.1, L501.2, R503.1, TP505.1 (1_1), U201.G7 (VCCPINT[6]), U201.G11 (VCCBRAM[2]), U201.G13 (VCCINT[9]), U201.H10 (VCCBRAM[2]), U201.H12 (VCCINT[9]), U201.J7 (VCCPINT[6]), U201.J13 (VCCINT[9]), U201.K12 (VCCINT[9]), U201.L7 (VCCPINT[6]), U201.L13 (VCCINT[9]), U201.M12 (VCCINT[9]), U201.N7 (VCCPINT[6]), U201.N13 (VCCINT[9]), U201.P8 (VCCPINT[6]), U201.P12 (VCCINT[9]), U201.R7 (VCCPINT[6]), U201.R13 (VCCINT[9]), U501.14 (VOS)
+1V5: C511.1, C545.1, C550.1, C556.1, C560.1, C566.1, C572.1, L502.2, R505.1, TP504.1 (1_1), U502.14 (VOS); also elsewhere on the board
+1V8: C522.1, C524.1, C526.1, C528.1, C534.1, C562.1, C568.1, C574.1, FB501.2, L503.2, R508.1, TP503.1 (1_1), U201.F8 (VCCPAUX[5]), U201.G9 (VCCPAUX[5]), U201.H8 (VCCPAUX[5]), U201.J11 (VCCAUX[6]), U201.K8 (VCCPAUX[5]), U201.L11 (VCCAUX[6]), U201.M8 (VCCPAUX[5]), U201.N9 (VCCAUX[6]), U201.N11 (VCCAUX[6]), U201.P10 (VCCAUX[6]), U201.R9 (VCCAUX[6]), U504.14 (VOS); also elsewhere on the board
+3V3: C517.1, C519.1, C540.1, C546.1, C551.1, C561.1, C567.1, C573.1, TP502.1 (1_1), U201.T8 (VCCO_13[4]), U201.U11 (VCCO_13[4]), U201.W7 (VCCO_13[4]), U201.Y10 (VCCO_13[4]), U503.5 (VOUT); also elsewhere on the board
+5V: C501.1, C502.1, C503.1, C504.1, C509.1, C512.1, C514.1, R501.1, R502.1, R507.1, TP501.1 (1_1), U501.10 (AVIN), U501.11 (PVIN_1), U501.12 (PVIN_2), U501.13 (EN), U502.10 (AVIN), U502.11 (PVIN_1), U502.12 (PVIN_2), U503.1 (VIN), U504.10 (AVIN), U504.11 (PVIN_1), U504.12 (PVIN_2); also elsewhere on the board
+VCCIO_34: C543.1, C548.1, C554.1, C558.1, C564.1, C570.1; also elsewhere on the board
+VCCIO_35: C544.1, C549.1, C555.1, C559.1, C565.1, C571.1; also elsewhere on the board
/POWER/1V0_PG: R501.2, U501.4 (PG), U504.13 (EN)
/POWER/1V0_SW: L501.1, U501.1 (SW_1), U501.2 (SW_2), U501.3 (SW_3)
/POWER/1V5_PG: R502.2, U502.4 (PG), U503.3 (EN)
/POWER/1V5_SW: L502.1, U502.1 (SW_1), U502.2 (SW_2), U502.3 (SW_3)
/POWER/1V8_PG: R507.2, U502.13 (EN), U504.4 (PG)
/POWER/1V8_SW: L503.1, U504.1 (SW_1), U504.2 (SW_2), U504.3 (SW_3)
GND: C501.2, C502.2, C503.2, C504.2, C505.1, C506.1, C507.2, C508.2, C509.2, C510.2, C511.2, C512.2, C514.2, C516.1, C517.2, C519.2, C521.2, C522.2, C523.2, C524.2, C525.2, C526.2, C527.2, C528.2, C530.2, C532.2, C533.2, C534.2, C536.2, C538.2, C539.2, C540.2, C542.2, C543.2, C544.2, C545.2, C546.2, C547.2, C548.2, C549.2, C550.2, C551.2, C552.2, C553.2, C554.2, C555.2, C556.2, C558.2, C559.2, C560.2, C561.2, C562.2, C563.2, C564.2, C565.2, C566.2, C567.2, C568.2, C569.2, C570.2, C571.2, C572.2, C573.2, C574.2, C575.2, R504.2, R506.2, R509.2, U201.A8 (GND[59]), U201.A18 (GND[59]), U201.B1 (GND[59]), U201.B11 (GND[59]), U201.C4 (GND[59]), U201.C9 (GND[59]), U201.C14 (GND[59]), U201.D17 (GND[59]), U201.E10 (GND[59]), U201.E20 (GND[59]), U201.F3 (GND[59]), U201.F7 (GND[59]), U201.G10 (GND[59]), U201.G12 (GND[59]), U201.G16 (GND[59]), U201.H7 (GND[59]), U201.H9 (GND[59]), U201.H11 (GND[59]), U201.H13 (GND[59]), U201.H19 (GND[59]), U201.J2 (GND[59]), U201.J8 (GND[59]), U201.J12 (GND[59]), U201.K5 (GND[59]), U201.K7 (GND[59]), U201.K11 (GND[59]), U201.K13 (GND[59]), U201.K15 (GND[59]), U201.L8 (GND[59]), U201.L12 (GND[59]), U201.L18 (GND[59]), U201.M1 (GND[59]), U201.M7 (GND[59]), U201.M11 (GND[59]), U201.M13 (GND[59]), U201.N4 (GND[59]), U201.N8 (GND[59]), U201.N10 (GND[59]), U201.N12 (GND[59]), U201.N14 (GND[59]), U201.P7 (GND[59]), U201.P9 (GND[59]), U201.P11 (GND[59]), U201.P13 (GND[59]), U201.P17 (GND[59]), U201.R8 (GND[59]), U201.R12 (GND[59]), U201.R20 (GND[59]), U201.T3 (GND[59]), U201.T7 (GND[59]), U201.T13 (GND[59]), U201.U6 (GND[59]), U201.U16 (GND[59]), U201.V9 (GND[59]), U201.V19 (GND[59]), U201.W2 (GND[59]), U201.W12 (GND[59]), U201.Y5 (GND[59]), U201.Y15 (GND[59]), U501.6 (AGND), U501.7 (FSW), U501.8 (DEF), U501.15 (PGND_1), U501.16 (PGND_2), U501.17 (EP), U502.6 (AGND), U502.7 (FSW), U502.8 (DEF), U502.15 (PGND_1), U502.16 (PGND_2), U502.17 (EP), U503.2 (GND), U504.6 (AGND), U504.7 (FSW), U504.8 (DEF), U504.15 (PGND_1), U504.16 (PGND_2), U504.17 (EP); also elsewhere on the board
unnamed: C507.1, C508.1, FB501.1, U201.G8 (VCCPLL)
unnamed: R503.2, R504.1, U501.5 (FB)
unnamed: C505.2, U501.9 (SS/TR)
unnamed: R505.2, R506.1, U502.5 (FB)
unnamed: C506.2, U502.9 (SS/TR)
unnamed: R508.2, R509.1, U504.5 (FB)
unnamed: C516.2, U504.9 (SS/TR)

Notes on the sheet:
VCC_BRAM
VCCINT
VCCO_DDR_502
VCC_PAUX
VCC_PINT
VCCO_MIO_501
VCCIO 35
VCCIO 34
VCC_AUX
VCCO_MIO_500

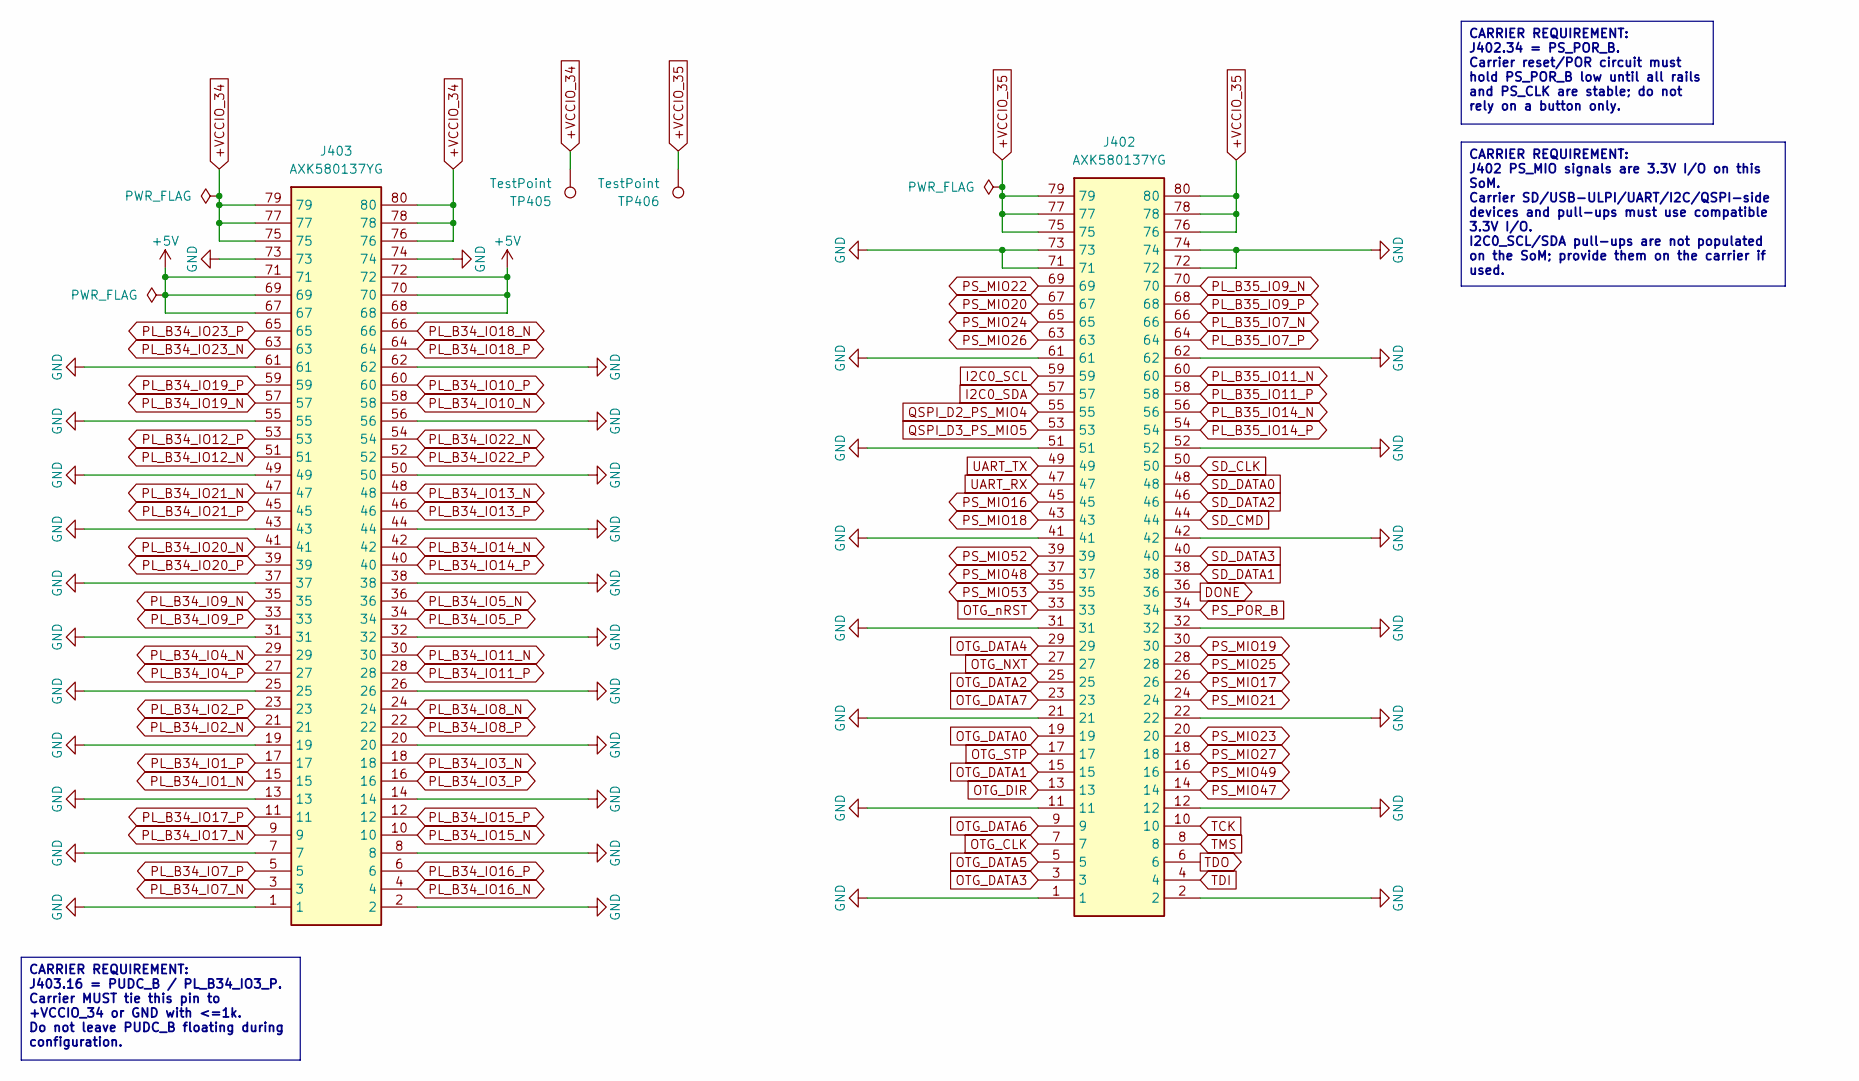
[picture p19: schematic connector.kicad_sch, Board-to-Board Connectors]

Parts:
J402, J403: AXK580137YG; Manufacturer_Part_Number AXK580137YG; Mouser Part Number 769-AXK580137YG
TP405, TP406: TestPoint; TestPoint_Pad_D1.0mm

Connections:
+5V: J403.67, J403.68, J403.69, J403.70, J403.71, J403.72; also elsewhere on the board
+VCCIO_34: J403.75, J403.76, J403.77, J403.78, J403.79, J403.80, TP405.1 (1_1); also elsewhere on the board
+VCCIO_35: J402.75, J402.76, J402.77, J402.78, J402.79, J402.80, TP406.1 (1_1); also elsewhere on the board
DONE: J402.36; also elsewhere on the board
GND: J402.1, J402.2, J402.11, J402.12, J402.21, J402.22, J402.31, J402.32, J402.41, J402.42, J402.51, J402.52, J402.61, J402.62, J402.71, J402.72, J402.73, J402.74, J403.1, J403.2, J403.7, J403.8, J403.13, J403.14, J403.19, J403.20, J403.25, J403.26, J403.31, J403.32, J403.37, J403.38, J403.43, J403.44, J403.49, J403.50, J403.55, J403.56, J403.61, J403.62, J403.73, J403.74; also elsewhere on the board
I2C0_SCL: J402.59; also elsewhere on the board
I2C0_SDA: J402.57; also elsewhere on the board
OTG_CLK: J402.7; also elsewhere on the board
OTG_DATA0: J402.19; also elsewhere on the board
OTG_DATA1: J402.15; also elsewhere on the board
OTG_DATA2: J402.25; also elsewhere on the board
OTG_DATA3: J402.3; also elsewhere on the board
OTG_DATA4: J402.29; also elsewhere on the board
OTG_DATA5: J402.5; also elsewhere on the board
OTG_DATA6: J402.9; also elsewhere on the board
OTG_DATA7: J402.23; also elsewhere on the board
OTG_DIR: J402.13; also elsewhere on the board
OTG_NXT: J402.27; also elsewhere on the board
OTG_STP: J402.17; also elsewhere on the board
OTG_nRST: J402.33; also elsewhere on the board
PL_B34_IO1_N: J403.15; also elsewhere on the board
PL_B34_IO1_P: J403.17; also elsewhere on the board
PL_B34_IO2_N: J403.21; also elsewhere on the board
PL_B34_IO2_P: J403.23; also elsewhere on the board
PL_B34_IO3_N: J403.18; also elsewhere on the board
PL_B34_IO3_P: J403.16; also elsewhere on the board
PL_B34_IO4_N: J403.29; also elsewhere on the board
PL_B34_IO4_P: J403.27; also elsewhere on the board
PL_B34_IO5_N: J403.36; also elsewhere on the board
PL_B34_IO5_P: J403.34; also elsewhere on the board
PL_B34_IO7_N: J403.3; also elsewhere on the board
PL_B34_IO7_P: J403.5; also elsewhere on the board
PL_B34_IO8_N: J403.24; also elsewhere on the board
PL_B34_IO8_P: J403.22; also elsewhere on the board
PL_B34_IO9_N: J403.35; also elsewhere on the board
PL_B34_IO9_P: J403.33; also elsewhere on the board
PL_B34_IO10_N: J403.58; also elsewhere on the board
PL_B34_IO10_P: J403.60; also elsewhere on the board
PL_B34_IO11_N: J403.30; also elsewhere on the board
PL_B34_IO11_P: J403.28; also elsewhere on the board
PL_B34_IO12_N: J403.51; also elsewhere on the board
PL_B34_IO12_P: J403.53; also elsewhere on the board
PL_B34_IO13_N: J403.48; also elsewhere on the board
PL_B34_IO13_P: J403.46; also elsewhere on the board
PL_B34_IO14_N: J403.42; also elsewhere on the board
PL_B34_IO14_P: J403.40; also elsewhere on the board
PL_B34_IO15_N: J403.10; also elsewhere on the board
PL_B34_IO15_P: J403.12; also elsewhere on the board
PL_B34_IO16_N: J403.4; also elsewhere on the board
PL_B34_IO16_P: J403.6; also elsewhere on the board
PL_B34_IO17_N: J403.9; also elsewhere on the board
PL_B34_IO17_P: J403.11; also elsewhere on the board
PL_B34_IO18_N: J403.66; also elsewhere on the board
PL_B34_IO18_P: J403.64; also elsewhere on the board
PL_B34_IO19_N: J403.57; also elsewhere on the board
PL_B34_IO19_P: J403.59; also elsewhere on the board
PL_B34_IO20_N: J403.41; also elsewhere on the board
PL_B34_IO20_P: J403.39; also elsewhere on the board
PL_B34_IO21_N: J403.47; also elsewhere on the board
PL_B34_IO21_P: J403.45; also elsewhere on the board
PL_B34_IO22_N: J403.54; also elsewhere on the board
PL_B34_IO22_P: J403.52; also elsewhere on the board
PL_B34_IO23_N: J403.63; also elsewhere on the board
PL_B34_IO23_P: J403.65; also elsewhere on the board
PL_B35_IO7_N: J402.66; also elsewhere on the board
PL_B35_IO7_P: J402.64; also elsewhere on the board
PL_B35_IO9_N: J402.70; also elsewhere on the board
PL_B35_IO9_P: J402.68; also elsewhere on the board
PL_B35_IO11_N: J402.60; also elsewhere on the board
PL_B35_IO11_P: J402.58; also elsewhere on the board
PL_B35_IO14_N: J402.56; also elsewhere on the board
PL_B35_IO14_P: J402.54; also elsewhere on the board
PS_MIO16: J402.45; also elsewhere on the board
PS_MIO17: J402.26; also elsewhere on the board
PS_MIO18: J402.43; also elsewhere on the board
PS_MIO19: J402.30; also elsewhere on the board
PS_MIO20: J402.67; also elsewhere on the board
PS_MIO21: J402.24; also elsewhere on the board
PS_MIO22: J402.69; also elsewhere on the board
PS_MIO23: J402.20; also elsewhere on the board
PS_MIO24: J402.65; also elsewhere on the board
PS_MIO25: J402.28; also elsewhere on the board
PS_MIO26: J402.63; also elsewhere on the board
PS_MIO27: J402.18; also elsewhere on the board
PS_MIO47: J402.14; also elsewhere on the board
PS_MIO48: J402.37; also elsewhere on the board
PS_MIO49: J402.16; also elsewhere on the board
PS_MIO52: J402.39; also elsewhere on the board
PS_MIO53: J402.35; also elsewhere on the board
PS_POR_B: J402.34; also elsewhere on the board
QSPI_D2_PS_MIO4: J402.55; also elsewhere on the board
QSPI_D3_PS_MIO5: J402.53; also elsewhere on the board
SD_CLK: J402.50; also elsewhere on the board
SD_CMD: J402.44; also elsewhere on the board
SD_DATA0: J402.48; also elsewhere on the board
SD_DATA1: J402.38; also elsewhere on the board
SD_DATA2: J402.46; also elsewhere on the board
SD_DATA3: J402.40; also elsewhere on the board
TCK: J402.10; also elsewhere on the board
TDI: J402.4; also elsewhere on the board
TDO: J402.6; also elsewhere on the board
TMS: J402.8; also elsewhere on the board
UART_RX: J402.47; also elsewhere on the board
UART_TX: J402.49; also elsewhere on the board

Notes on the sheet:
CARRIER REQUIREMENT: J403.16 = PUDC_B / PL_B34_IO3_P. Carrier MUST tie this pin to +VCCIO_34 or GND with <=1k. Do not leave PUDC_B floating during configuration.
CARRIER REQUIREMENT: J402.34 = PS_POR_B. Carrier reset/POR circuit must hold PS_POR_B low until all rails and PS_CLK are stable; do not rely on a button only.
CARRIER REQUIREMENT: J402 PS_MIO signals are 3.3V I/O on this SoM. Carrier SD/USB-ULPI/UART/I2C/QSPI-side devices and pull-ups must use compatible 3.3V I/O. I2C0_SCL/SDA pull-ups are not populated on the SoM; provide them on the carrier if used.

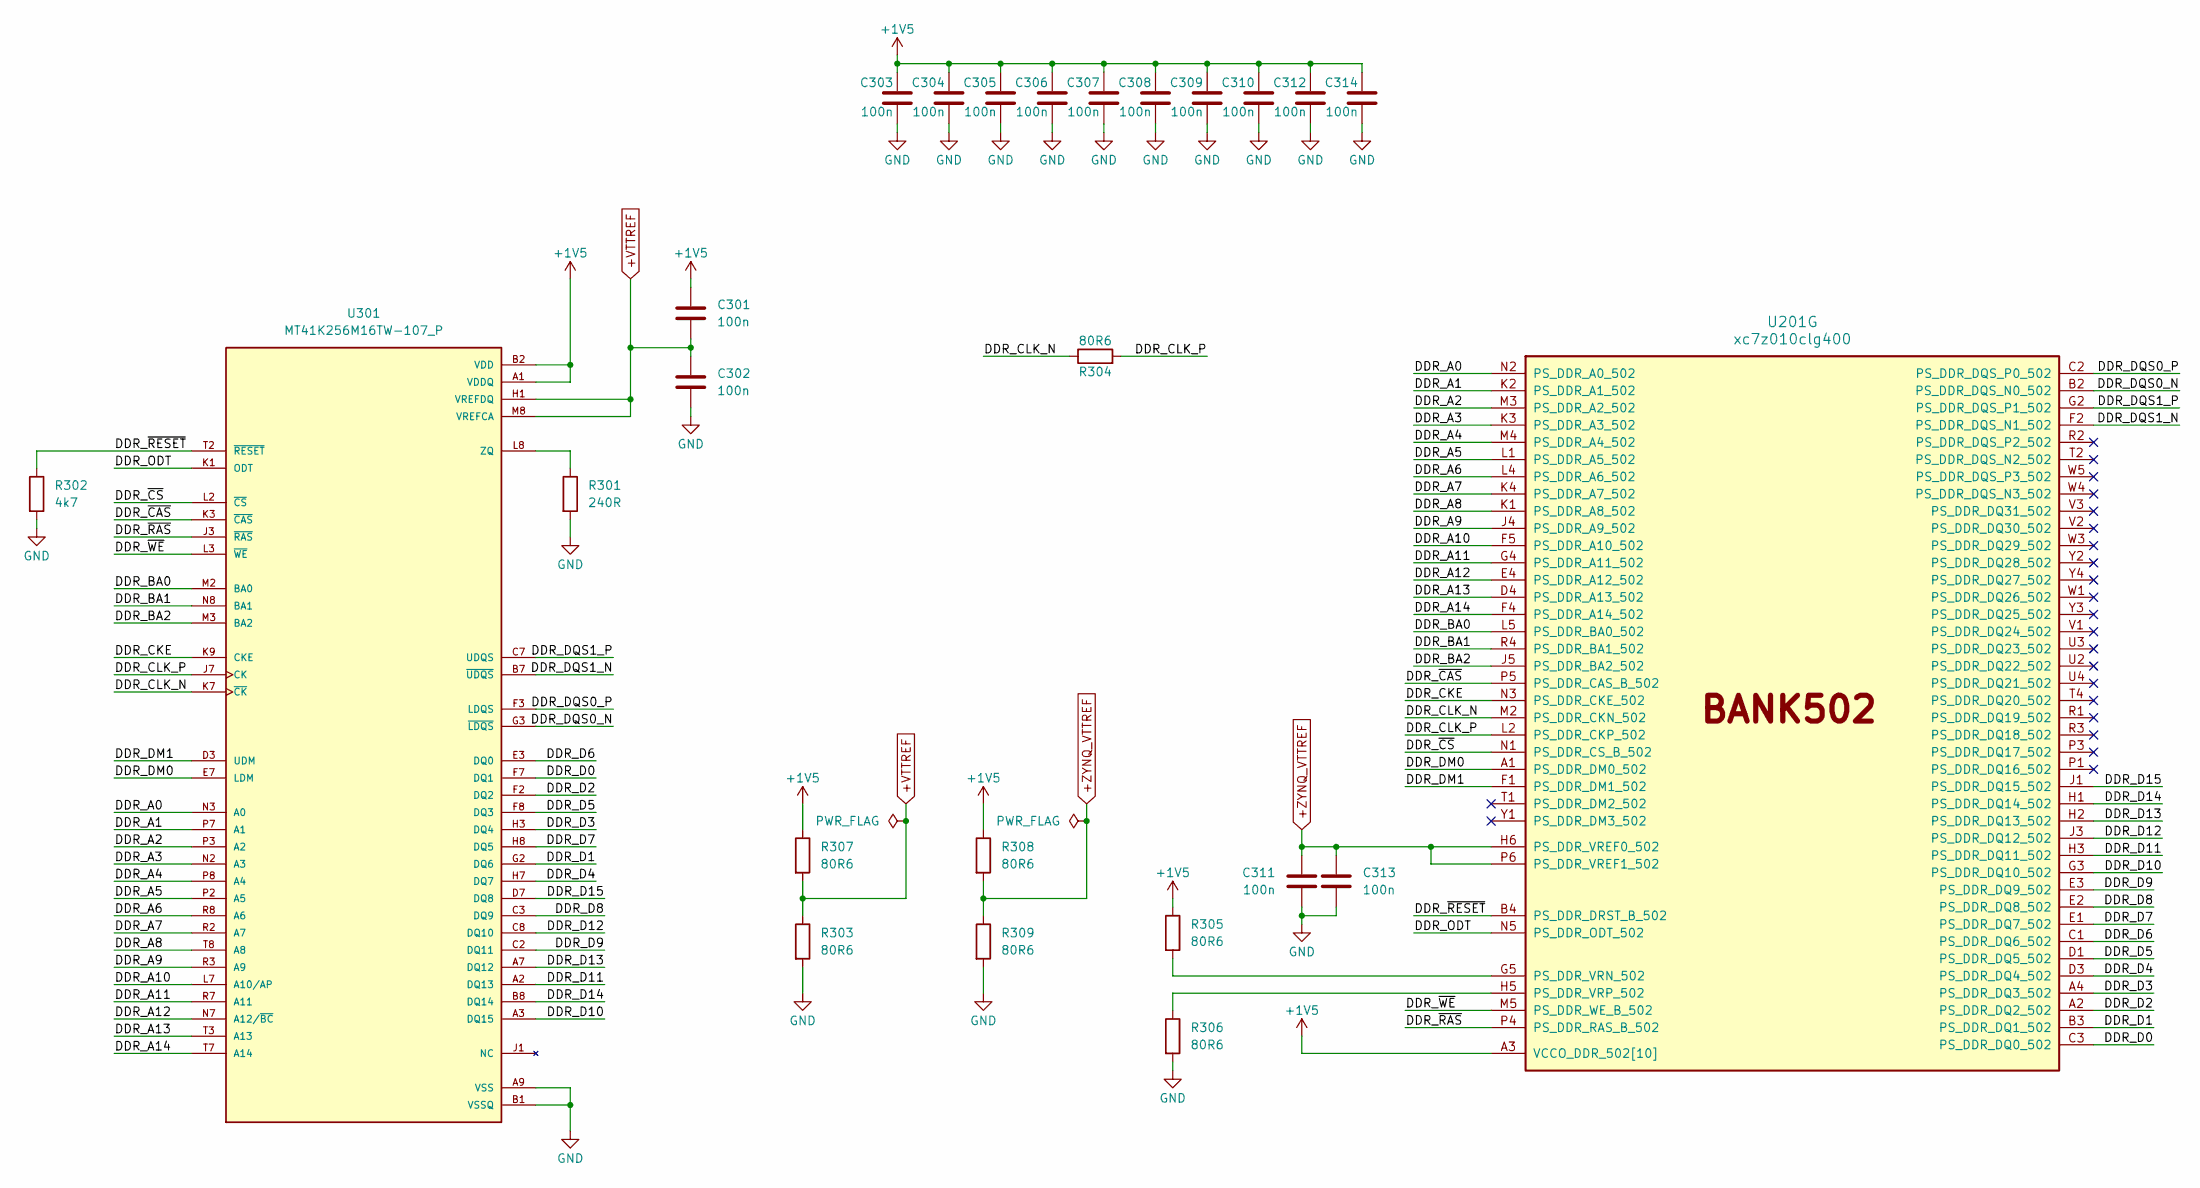
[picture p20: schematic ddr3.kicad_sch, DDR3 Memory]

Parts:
C301, C302, C303, C304, C305, C306, C307, C308, C309, C310, C311, C312, C313, C314: 100n; C_0402_1005Metric
R301: 240R; R_0402_1005Metric
R302: 4k7; R_0402_1005Metric
R303, R304, R305, R306, R307, R308, R309: 80R6; R_0402_1005Metric
U201: xc7z010clg400; Xilinx_CLG400
U301: MT41K256M16TW-107_P; BGA96C80P9X16_1400X800X120; PARTREV P

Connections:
+1V5: C301.1, C303.1, C304.1, C305.1, C306.1, C307.1, C308.1, C309.1, C310.1, C312.1, C314.1, R305.1, R307.1, R308.1, U201.A3 (VCCO_DDR_502[10]), U201.D2 (VCCO_DDR_502[10]), U201.E5 (VCCO_DDR_502[10]), U201.G1 (VCCO_DDR_502[10]), U201.H4 (VCCO_DDR_502[10]), U201.L3 (VCCO_DDR_502[10]), U201.P2 (VCCO_DDR_502[10]), U201.R5 (VCCO_DDR_502[10]), U201.U1 (VCCO_DDR_502[10]), U201.V4 (VCCO_DDR_502[10]), U301.A1 (VDDQ), U301.A8 (VDDQ), U301.B2 (VDD), U301.C1 (VDDQ), U301.C9 (VDDQ), U301.D2 (VDDQ), U301.D9 (VDD), U301.E9 (VDDQ), U301.F1 (VDDQ), U301.G7 (VDD), U301.H2 (VDDQ), U301.H9 (VDDQ), U301.K2 (VDD), U301.K8 (VDD), U301.N1 (VDD), U301.N9 (VDD), U301.R1 (VDD), U301.R9 (VDD); also elsewhere on the board
+VTTREF: C301.2, C302.1, R303.1, R307.2, U301.H1 (VREFDQ), U301.M8 (VREFCA)
+ZYNQ_VTTREF: C311.1, C313.1, R308.2, R309.1, U201.H6 (PS_DDR_VREF0_502), U201.P6 (PS_DDR_VREF1_502)
/DDR3/DDR_A0: U201.N2 (PS_DDR_A0_502), U301.N3 (A0)
/DDR3/DDR_A1: U201.K2 (PS_DDR_A1_502), U301.P7 (A1)
/DDR3/DDR_A2: U201.M3 (PS_DDR_A2_502), U301.P3 (A2)
/DDR3/DDR_A3: U201.K3 (PS_DDR_A3_502), U301.N2 (A3)
/DDR3/DDR_A4: U201.M4 (PS_DDR_A4_502), U301.P8 (A4)
/DDR3/DDR_A5: U201.L1 (PS_DDR_A5_502), U301.P2 (A5)
/DDR3/DDR_A6: U201.L4 (PS_DDR_A6_502), U301.R8 (A6)
/DDR3/DDR_A7: U201.K4 (PS_DDR_A7_502), U301.R2 (A7)
/DDR3/DDR_A8: U201.K1 (PS_DDR_A8_502), U301.T8 (A8)
/DDR3/DDR_A9: U201.J4 (PS_DDR_A9_502), U301.R3 (A9)
/DDR3/DDR_A10: U201.F5 (PS_DDR_A10_502), U301.L7 (A10/AP)
/DDR3/DDR_A11: U201.G4 (PS_DDR_A11_502), U301.R7 (A11)
/DDR3/DDR_A12: U201.E4 (PS_DDR_A12_502), U301.N7 (A12/~BC)
/DDR3/DDR_A13: U201.D4 (PS_DDR_A13_502), U301.T3 (A13)
/DDR3/DDR_A14: U201.F4 (PS_DDR_A14_502), U301.T7 (A14)
/DDR3/DDR_BA0: U201.L5 (PS_DDR_BA0_502), U301.M2 (BA0)
/DDR3/DDR_BA1: U201.R4 (PS_DDR_BA1_502), U301.N8 (BA1)
/DDR3/DDR_BA2: U201.J5 (PS_DDR_BA2_502), U301.M3 (BA2)
/DDR3/DDR_CKE: U201.N3 (PS_DDR_CKE_502), U301.K9 (CKE)
/DDR3/DDR_CLK_N: R304.1, U201.M2 (PS_DDR_CKN_502), U301.K7 (~CK)
/DDR3/DDR_CLK_P: R304.2, U201.L2 (PS_DDR_CKP_502), U301.J7 (CK)
/DDR3/DDR_D0: U201.C3 (PS_DDR_DQ0_502), U301.F7 (DQ1)
/DDR3/DDR_D1: U201.B3 (PS_DDR_DQ1_502), U301.G2 (DQ6)
/DDR3/DDR_D2: U201.A2 (PS_DDR_DQ2_502), U301.F2 (DQ2)
/DDR3/DDR_D3: U201.A4 (PS_DDR_DQ3_502), U301.H3 (DQ4)
/DDR3/DDR_D4: U201.D3 (PS_DDR_DQ4_502), U301.H7 (DQ7)
/DDR3/DDR_D5: U201.D1 (PS_DDR_DQ5_502), U301.F8 (DQ3)
/DDR3/DDR_D6: U201.C1 (PS_DDR_DQ6_502), U301.E3 (DQ0)
/DDR3/DDR_D7: U201.E1 (PS_DDR_DQ7_502), U301.H8 (DQ5)
/DDR3/DDR_D8: U201.E2 (PS_DDR_DQ8_502), U301.C3 (DQ9)
/DDR3/DDR_D9: U201.E3 (PS_DDR_DQ9_502), U301.C2 (DQ11)
/DDR3/DDR_D10: U201.G3 (PS_DDR_DQ10_502), U301.A3 (DQ15)
/DDR3/DDR_D11: U201.H3 (PS_DDR_DQ11_502), U301.A2 (DQ13)
/DDR3/DDR_D12: U201.J3 (PS_DDR_DQ12_502), U301.C8 (DQ10)
/DDR3/DDR_D13: U201.H2 (PS_DDR_DQ13_502), U301.A7 (DQ12)
/DDR3/DDR_D14: U201.H1 (PS_DDR_DQ14_502), U301.B8 (DQ14)
/DDR3/DDR_D15: U201.J1 (PS_DDR_DQ15_502), U301.D7 (DQ8)
/DDR3/DDR_DM0: U201.A1 (PS_DDR_DM0_502), U301.E7 (LDM)
/DDR3/DDR_DM1: U201.F1 (PS_DDR_DM1_502), U301.D3 (UDM)
/DDR3/DDR_DQS0_N: U201.B2 (PS_DDR_DQS_N0_502), U301.G3 (~LDQS)
/DDR3/DDR_DQS0_P: U201.C2 (PS_DDR_DQS_P0_502), U301.F3 (LDQS)
/DDR3/DDR_DQS1_N: U201.F2 (PS_DDR_DQS_N1_502), U301.B7 (~UDQS)
/DDR3/DDR_DQS1_P: U201.G2 (PS_DDR_DQS_P1_502), U301.C7 (UDQS)
/DDR3/DDR_ODT: U201.N5 (PS_DDR_ODT_502), U301.K1 (ODT)
/DDR3/DDR_~CAS: U201.P5 (PS_DDR_CAS_B_502), U301.K3 (~CAS)
/DDR3/DDR_~CS: U201.N1 (PS_DDR_CS_B_502), U301.L2 (~CS)
/DDR3/DDR_~RAS: U201.P4 (PS_DDR_RAS_B_502), U301.J3 (~RAS)
/DDR3/DDR_~RESET: R302.1, U201.B4 (PS_DDR_DRST_B_502), U301.T2 (~RESET)
/DDR3/DDR_~WE: U201.M5 (PS_DDR_WE_B_502), U301.L3 (~WE)
GND: C302.2, C303.2, C304.2, C305.2, C306.2, C307.2, C308.2, C309.2, C310.2, C311.2, C312.2, C313.2, C314.2, R301.2, R302.2, R303.2, R306.2, R309.2, U301.A9 (VSS), U301.B1 (VSSQ), U301.B3 (VSS), U301.B9 (VSSQ), U301.D1 (VSSQ), U301.D8 (VSSQ), U301.E1 (VSS), U301.E2 (VSSQ), U301.E8 (VSSQ), U301.F9 (VSSQ), U301.G1 (VSSQ), U301.G8 (VSS), U301.G9 (VSSQ), U301.J2 (VSS), U301.J8 (VSS), U301.M1 (VSS), U301.M9 (VSS), U301.P1 (VSS), U301.P9 (VSS), U301.T1 (VSS), U301.T9 (VSS); also elsewhere on the board
unnamed: R305.2, U201.G5 (PS_DDR_VRN_502)
unnamed: R306.1, U201.H5 (PS_DDR_VRP_502)
unnamed: R301.1, U301.L8 (ZQ)

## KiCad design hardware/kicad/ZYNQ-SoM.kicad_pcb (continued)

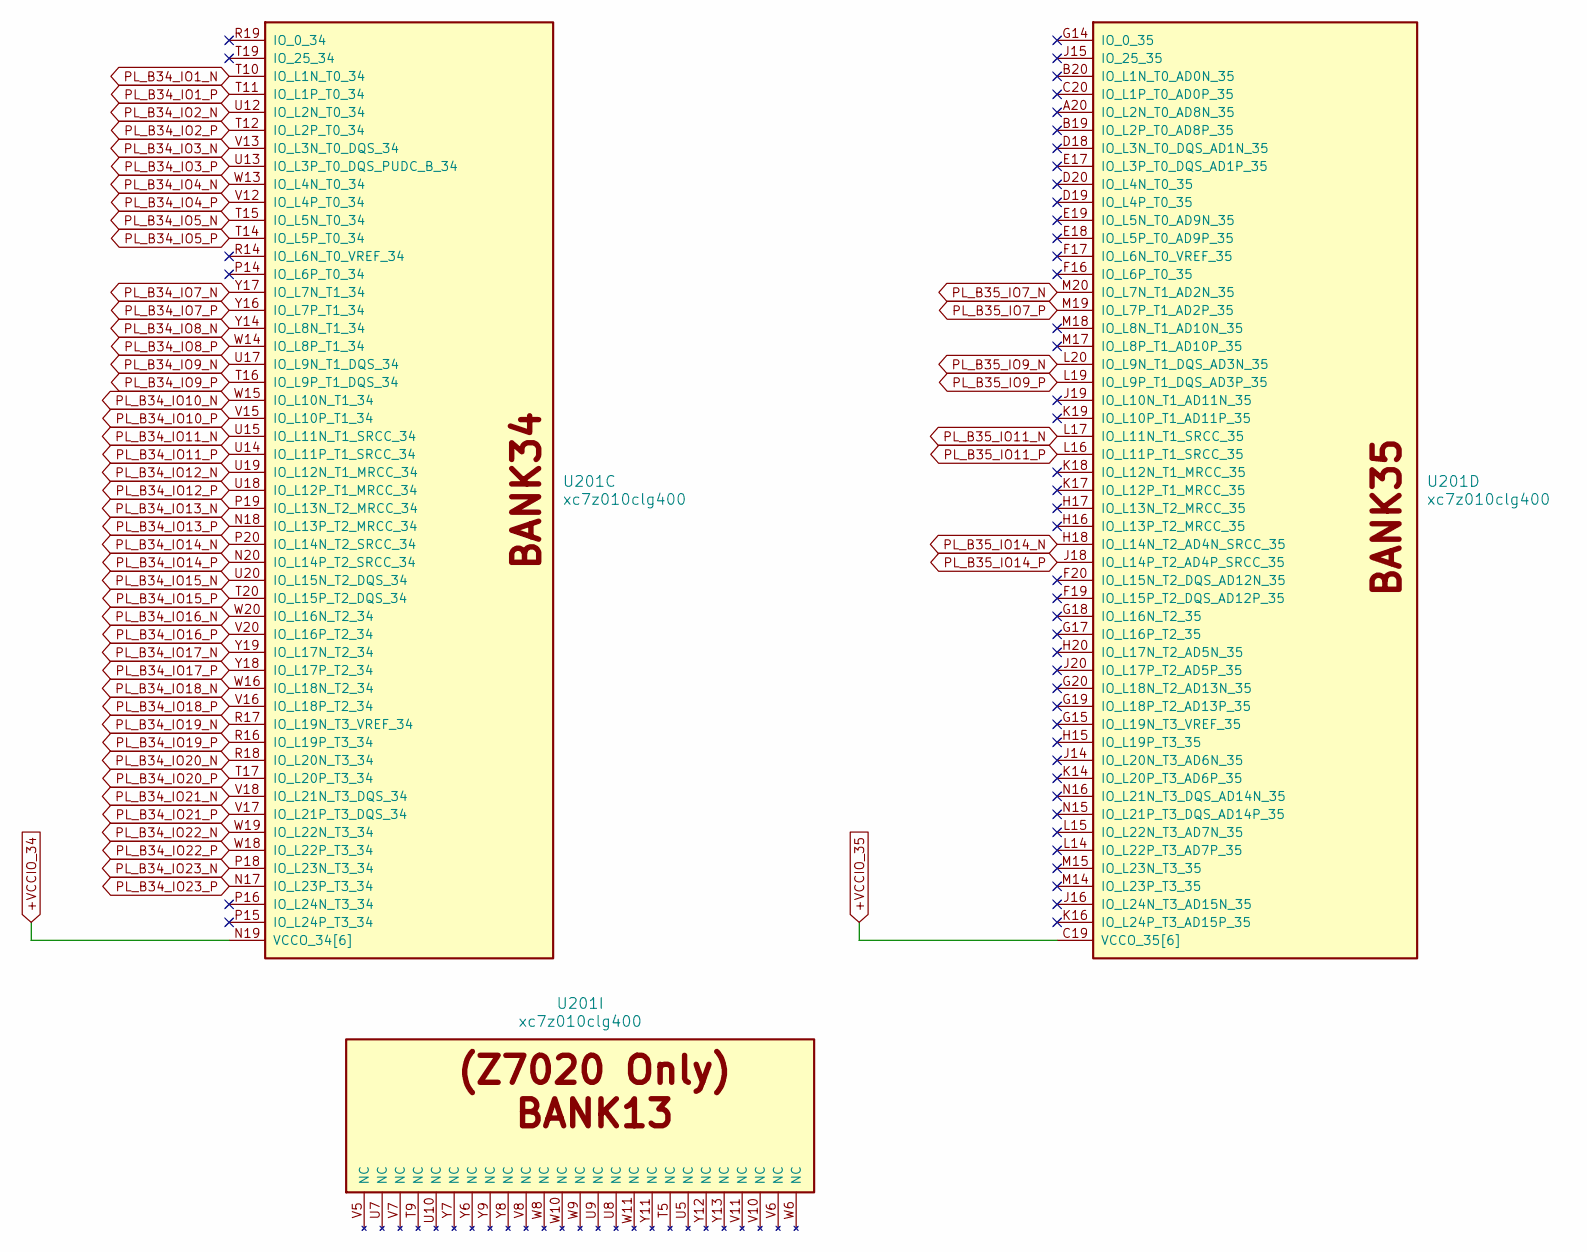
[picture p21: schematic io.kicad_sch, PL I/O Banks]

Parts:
U201: xc7z010clg400; Xilinx_CLG400

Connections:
+VCCIO_34: U201.N19 (VCCO_34[6]), U201.R15 (VCCO_34[6]), U201.T18 (VCCO_34[6]), U201.V14 (VCCO_34[6]), U201.W17 (VCCO_34[6]), U201.Y20 (VCCO_34[6]); also elsewhere on the board
+VCCIO_35: U201.C19 (VCCO_35[6]), U201.F18 (VCCO_35[6]), U201.H14 (VCCO_35[6]), U201.J17 (VCCO_35[6]), U201.K20 (VCCO_35[6]), U201.M16 (VCCO_35[6]); also elsewhere on the board
PL_B34_IO1_N: U201.T10 (IO_L1N_T0_34); also elsewhere on the board
PL_B34_IO1_P: U201.T11 (IO_L1P_T0_34); also elsewhere on the board
PL_B34_IO2_N: U201.U12 (IO_L2N_T0_34); also elsewhere on the board
PL_B34_IO2_P: U201.T12 (IO_L2P_T0_34); also elsewhere on the board
PL_B34_IO3_N: U201.V13 (IO_L3N_T0_DQS_34); also elsewhere on the board
PL_B34_IO3_P: U201.U13 (IO_L3P_T0_DQS_PUDC_B_34); also elsewhere on the board
PL_B34_IO4_N: U201.W13 (IO_L4N_T0_34); also elsewhere on the board
PL_B34_IO4_P: U201.V12 (IO_L4P_T0_34); also elsewhere on the board
PL_B34_IO5_N: U201.T15 (IO_L5N_T0_34); also elsewhere on the board
PL_B34_IO5_P: U201.T14 (IO_L5P_T0_34); also elsewhere on the board
PL_B34_IO7_N: U201.Y17 (IO_L7N_T1_34); also elsewhere on the board
PL_B34_IO7_P: U201.Y16 (IO_L7P_T1_34); also elsewhere on the board
PL_B34_IO8_N: U201.Y14 (IO_L8N_T1_34); also elsewhere on the board
PL_B34_IO8_P: U201.W14 (IO_L8P_T1_34); also elsewhere on the board
PL_B34_IO9_N: U201.U17 (IO_L9N_T1_DQS_34); also elsewhere on the board
PL_B34_IO9_P: U201.T16 (IO_L9P_T1_DQS_34); also elsewhere on the board
PL_B34_IO10_N: U201.W15 (IO_L10N_T1_34); also elsewhere on the board
PL_B34_IO10_P: U201.V15 (IO_L10P_T1_34); also elsewhere on the board
PL_B34_IO11_N: U201.U15 (IO_L11N_T1_SRCC_34); also elsewhere on the board
PL_B34_IO11_P: U201.U14 (IO_L11P_T1_SRCC_34); also elsewhere on the board
PL_B34_IO12_N: U201.U19 (IO_L12N_T1_MRCC_34); also elsewhere on the board
PL_B34_IO12_P: U201.U18 (IO_L12P_T1_MRCC_34); also elsewhere on the board
PL_B34_IO13_N: U201.P19 (IO_L13N_T2_MRCC_34); also elsewhere on the board
PL_B34_IO13_P: U201.N18 (IO_L13P_T2_MRCC_34); also elsewhere on the board
PL_B34_IO14_N: U201.P20 (IO_L14N_T2_SRCC_34); also elsewhere on the board
PL_B34_IO14_P: U201.N20 (IO_L14P_T2_SRCC_34); also elsewhere on the board
PL_B34_IO15_N: U201.U20 (IO_L15N_T2_DQS_34); also elsewhere on the board
PL_B34_IO15_P: U201.T20 (IO_L15P_T2_DQS_34); also elsewhere on the board
PL_B34_IO16_N: U201.W20 (IO_L16N_T2_34); also elsewhere on the board
PL_B34_IO16_P: U201.V20 (IO_L16P_T2_34); also elsewhere on the board
PL_B34_IO17_N: U201.Y19 (IO_L17N_T2_34); also elsewhere on the board
PL_B34_IO17_P: U201.Y18 (IO_L17P_T2_34); also elsewhere on the board
PL_B34_IO18_N: U201.W16 (IO_L18N_T2_34); also elsewhere on the board
PL_B34_IO18_P: U201.V16 (IO_L18P_T2_34); also elsewhere on the board
PL_B34_IO19_N: U201.R17 (IO_L19N_T3_VREF_34); also elsewhere on the board
PL_B34_IO19_P: U201.R16 (IO_L19P_T3_34); also elsewhere on the board
PL_B34_IO20_N: U201.R18 (IO_L20N_T3_34); also elsewhere on the board
PL_B34_IO20_P: U201.T17 (IO_L20P_T3_34); also elsewhere on the board
PL_B34_IO21_N: U201.V18 (IO_L21N_T3_DQS_34); also elsewhere on the board
PL_B34_IO21_P: U201.V17 (IO_L21P_T3_DQS_34); also elsewhere on the board
PL_B34_IO22_N: U201.W19 (IO_L22N_T3_34); also elsewhere on the board
PL_B34_IO22_P: U201.W18 (IO_L22P_T3_34); also elsewhere on the board
PL_B34_IO23_N: U201.P18 (IO_L23N_T3_34); also elsewhere on the board
PL_B34_IO23_P: U201.N17 (IO_L23P_T3_34); also elsewhere on the board
PL_B35_IO7_N: U201.M20 (IO_L7N_T1_AD2N_35); also elsewhere on the board
PL_B35_IO7_P: U201.M19 (IO_L7P_T1_AD2P_35); also elsewhere on the board
PL_B35_IO9_N: U201.L20 (IO_L9N_T1_DQS_AD3N_35); also elsewhere on the board
PL_B35_IO9_P: U201.L19 (IO_L9P_T1_DQS_AD3P_35); also elsewhere on the board
PL_B35_IO11_N: U201.L17 (IO_L11N_T1_SRCC_35); also elsewhere on the board
PL_B35_IO11_P: U201.L16 (IO_L11P_T1_SRCC_35); also elsewhere on the board
PL_B35_IO14_N: U201.H18 (IO_L14N_T2_AD4N_SRCC_35); also elsewhere on the board
PL_B35_IO14_P: U201.J18 (IO_L14P_T2_AD4P_SRCC_35); also elsewhere on the board

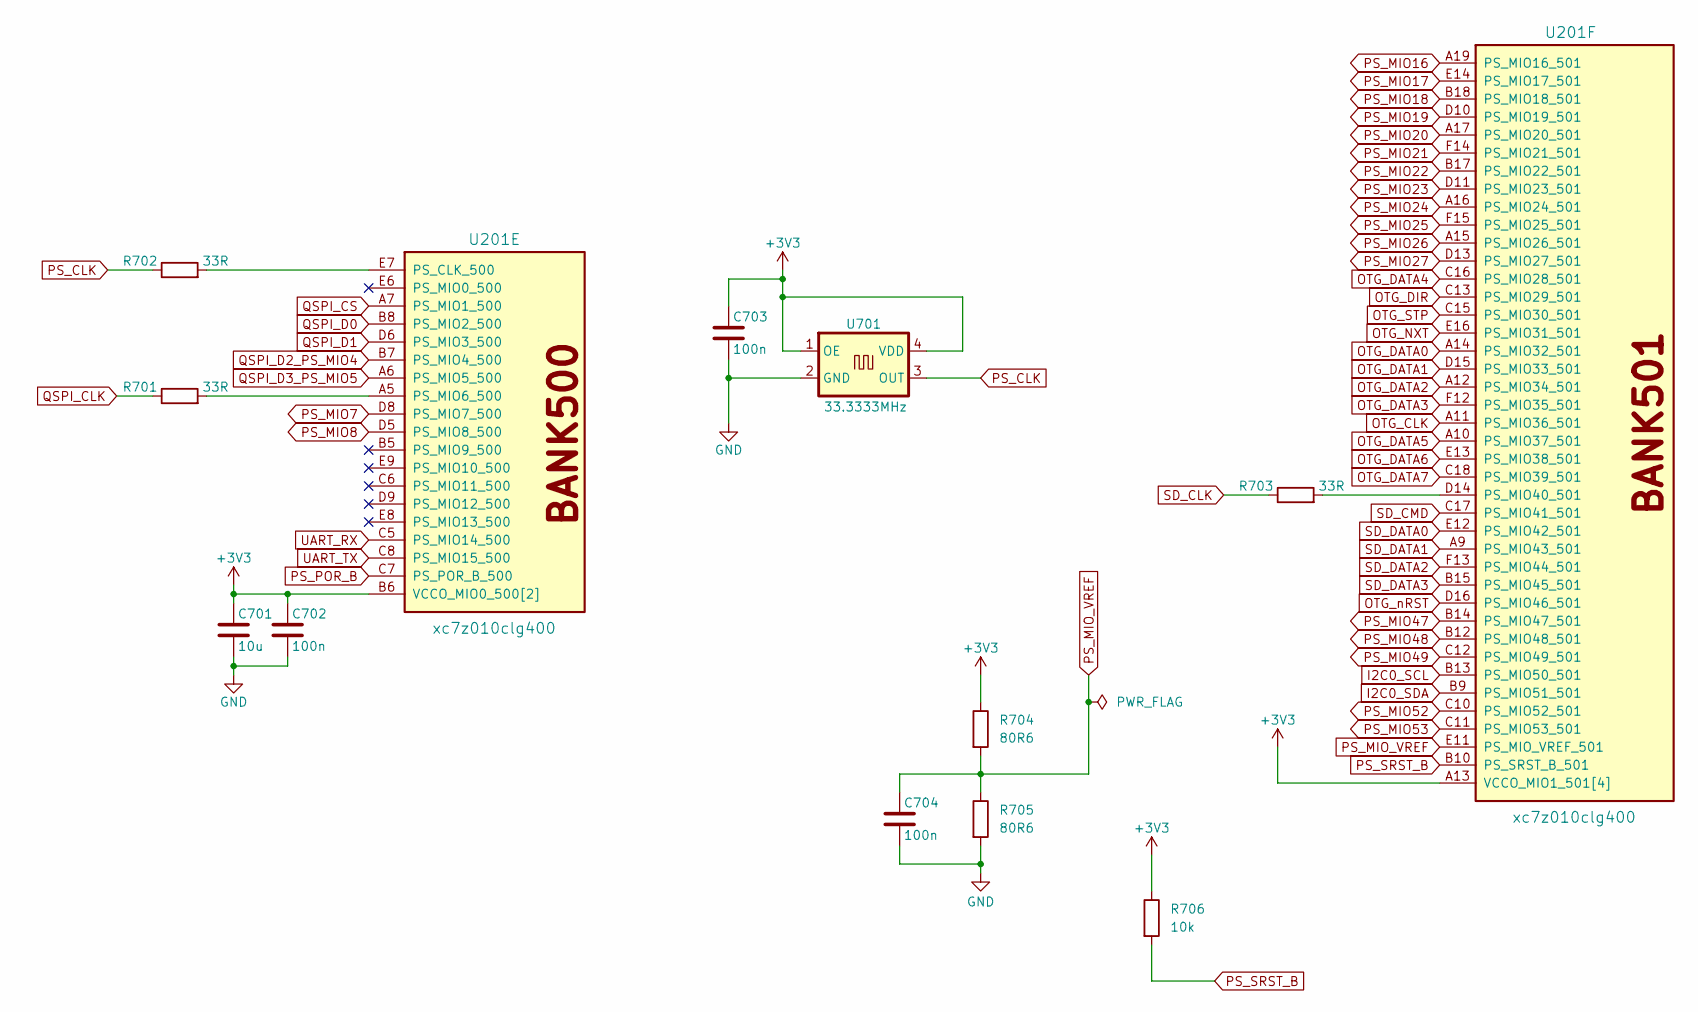
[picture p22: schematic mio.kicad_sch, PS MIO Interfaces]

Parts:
C701: 10u; C_0805_2012Metric
C702, C703, C704: 100n; C_0402_1005Metric
R701, R702, R703: 33R; R_0402_1005Metric
R704, R705: 80R6; R_0402_1005Metric
R706: 10k; R_0402_1005Metric
U201: xc7z010clg400; Xilinx_CLG400
U701: 33.3333MHz; Oscillator_SMD_SeikoEpson_SG8002CE-4Pin_3.2x2.5mm

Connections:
+3V3: C701.1, C702.1, C703.1, R704.1, R706.1, U201.A13 (VCCO_MIO1_501[4]), U201.B6 (VCCO_MIO0_500[2]), U201.B16 (VCCO_MIO1_501[4]), U201.D7 (VCCO_MIO0_500[2]), U201.D12 (VCCO_MIO1_501[4]), U201.E15 (VCCO_MIO1_501[4]), U701.1 (OE), U701.4 (VDD); also elsewhere on the board
GND: C701.2, C702.2, C703.2, C704.2, R705.2, U701.2 (GND); also elsewhere on the board
I2C0_SCL: U201.B13 (PS_MIO50_501); also elsewhere on the board
I2C0_SDA: U201.B9 (PS_MIO51_501); also elsewhere on the board
unnamed: R702.2, U201.E7 (PS_CLK_500)
unnamed: R701.2, U201.A5 (PS_MIO6_500)
unnamed: R703.2, U201.D14 (PS_MIO40_501)
OTG_CLK: U201.A11 (PS_MIO36_501); also elsewhere on the board
OTG_DATA0: U201.A14 (PS_MIO32_501); also elsewhere on the board
OTG_DATA1: U201.D15 (PS_MIO33_501); also elsewhere on the board
OTG_DATA2: U201.A12 (PS_MIO34_501); also elsewhere on the board
OTG_DATA3: U201.F12 (PS_MIO35_501); also elsewhere on the board
OTG_DATA4: U201.C16 (PS_MIO28_501); also elsewhere on the board
OTG_DATA5: U201.A10 (PS_MIO37_501); also elsewhere on the board
OTG_DATA6: U201.E13 (PS_MIO38_501); also elsewhere on the board
OTG_DATA7: U201.C18 (PS_MIO39_501); also elsewhere on the board
OTG_DIR: U201.C13 (PS_MIO29_501); also elsewhere on the board
OTG_NXT: U201.E16 (PS_MIO31_501); also elsewhere on the board
OTG_STP: U201.C15 (PS_MIO30_501); also elsewhere on the board
OTG_nRST: U201.D16 (PS_MIO46_501); also elsewhere on the board
PS_CLK: R702.1, U701.3 (OUT)
PS_MIO7: U201.D8 (PS_MIO7_500); also elsewhere on the board
PS_MIO8: U201.D5 (PS_MIO8_500); also elsewhere on the board
PS_MIO16: U201.A19 (PS_MIO16_501); also elsewhere on the board
PS_MIO17: U201.E14 (PS_MIO17_501); also elsewhere on the board
PS_MIO18: U201.B18 (PS_MIO18_501); also elsewhere on the board
PS_MIO19: U201.D10 (PS_MIO19_501); also elsewhere on the board
PS_MIO20: U201.A17 (PS_MIO20_501); also elsewhere on the board
PS_MIO21: U201.F14 (PS_MIO21_501); also elsewhere on the board
PS_MIO22: U201.B17 (PS_MIO22_501); also elsewhere on the board
PS_MIO23: U201.D11 (PS_MIO23_501); also elsewhere on the board
PS_MIO24: U201.A16 (PS_MIO24_501); also elsewhere on the board
PS_MIO25: U201.F15 (PS_MIO25_501); also elsewhere on the board
PS_MIO26: U201.A15 (PS_MIO26_501); also elsewhere on the board
PS_MIO27: U201.D13 (PS_MIO27_501); also elsewhere on the board
PS_MIO47: U201.B14 (PS_MIO47_501); also elsewhere on the board
PS_MIO48: U201.B12 (PS_MIO48_501); also elsewhere on the board
PS_MIO49: U201.C12 (PS_MIO49_501); also elsewhere on the board
PS_MIO52: U201.C10 (PS_MIO52_501); also elsewhere on the board
PS_MIO53: U201.C11 (PS_MIO53_501); also elsewhere on the board
PS_MIO_VREF: C704.1, R704.2, R705.1, U201.E11 (PS_MIO_VREF_501)
PS_POR_B: U201.C7 (PS_POR_B_500); also elsewhere on the board
PS_SRST_B: R706.2, U201.B10 (PS_SRST_B_501)
QSPI_CLK: R701.1; also elsewhere on the board
QSPI_CS: U201.A7 (PS_MIO1_500); also elsewhere on the board
QSPI_D0: U201.B8 (PS_MIO2_500); also elsewhere on the board
QSPI_D1: U201.D6 (PS_MIO3_500); also elsewhere on the board
QSPI_D2_PS_MIO4: U201.B7 (PS_MIO4_500); also elsewhere on the board
QSPI_D3_PS_MIO5: U201.A6 (PS_MIO5_500); also elsewhere on the board
SD_CLK: R703.1; also elsewhere on the board
SD_CMD: U201.C17 (PS_MIO41_501); also elsewhere on the board
SD_DATA0: U201.E12 (PS_MIO42_501); also elsewhere on the board
SD_DATA1: U201.A9 (PS_MIO43_501); also elsewhere on the board
SD_DATA2: U201.F13 (PS_MIO44_501); also elsewhere on the board
SD_DATA3: U201.B15 (PS_MIO45_501); also elsewhere on the board
UART_RX: U201.C5 (PS_MIO14_500); also elsewhere on the board
UART_TX: U201.C8 (PS_MIO15_500); also elsewhere on the board

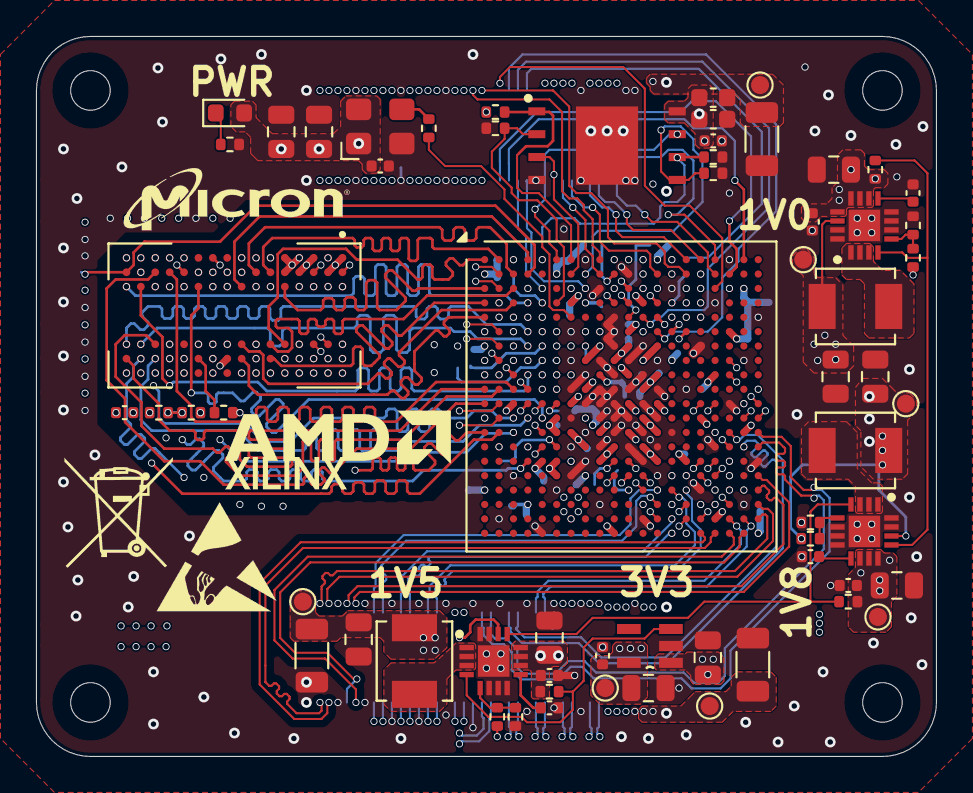
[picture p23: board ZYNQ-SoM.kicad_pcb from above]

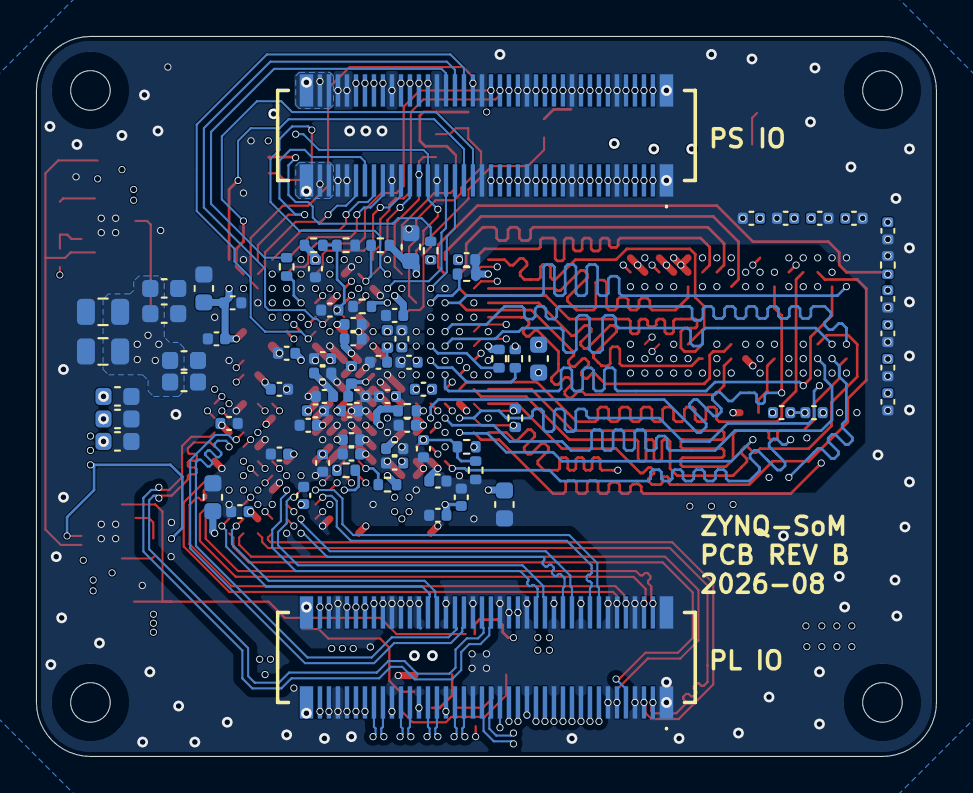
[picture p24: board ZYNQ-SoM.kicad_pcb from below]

Board: 6 copper layers, 50.0 x 40.0 mm, 147 parts (81 on the bottom side), 191 nets.

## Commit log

2026-06-07 Init commit
    [ZYNQ-SoM.kicad_pcb, ZYNQ-SoM.kicad_sch, bank0.kicad_sch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]
2026-06-07 feat: finish ddr sch design
    [ZYNQ-SoM.kicad_pcb, ddr3.kicad_sch]
2026-06-08 feat: finish power sch design
    [ZYNQ-SoM.kicad_pcb, ZYNQ-SoM.kicad_sch, bank0.kicad_sch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]
2026-06-08 feat: continue ps mio sch design
    [ZYNQ-SoM.kicad_pcb, ZYNQ-SoM.kicad_sch, ddr3.kicad_sch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]
2026-06-08 feat: continue PL sch design
    [io.kicad_sch, mio.kicad_sch]
2026-06-08 feat: continue improve sch design
    [ZYNQ-SoM.kicad_pcb, bank0.kicad_sch, connector.kicad_sch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]
2026-06-09 feat: basic power layout
    [ZYNQ-SoM.kicad_pcb]
2026-06-11 feat: finish basic ddr3 routing
    [ZYNQ-SoM.kicad_pcb, connector.kicad_sch, ddr3.kicad_sch]
2026-06-11 feat: need finish power layout
    [ZYNQ-SoM.kicad_pcb, connector.kicad_sch]
2026-06-12 layout: route mio and some io
    [ZYNQ-SoM.kicad_pcb, connector.kicad_sch, mio.kicad_sch]
2026-06-14 layout: continue layout pl io
    [ZYNQ-SoM.kicad_pcb, ZYNQ-SoM.kicad_sch, bank0.kicad_sch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]
2026-07-22 layout: routing bank 34
    [ZYNQ-SoM.kicad_pcb, ZYNQ-SoM.kicad_sch, bank0.kicad_sch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]
2026-07-22 layout: finish basic bank34 routing
    [ZYNQ-SoM.kicad_pcb]
2026-08-14 layout: before rerouting ddr
    [ZYNQ-SoM.kicad_pcb, bank0.kicad_sch, connector.kicad_sch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]
2026-08-14 layout: add bank 34 pl pair
    [ZYNQ-SoM.kicad_pcb, connector.kicad_sch, io.kicad_sch]
2026-09-09 chore: update info
    [ZYNQ-SoM-B_Cu [BOTTOM].gbr, ZYNQ-SoM-B_Mask.gbr, ZYNQ-SoM-B_Paste.gbr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]
2026-09-09 chore: update assembled img
2026-09-12 chore: update pcb photos
